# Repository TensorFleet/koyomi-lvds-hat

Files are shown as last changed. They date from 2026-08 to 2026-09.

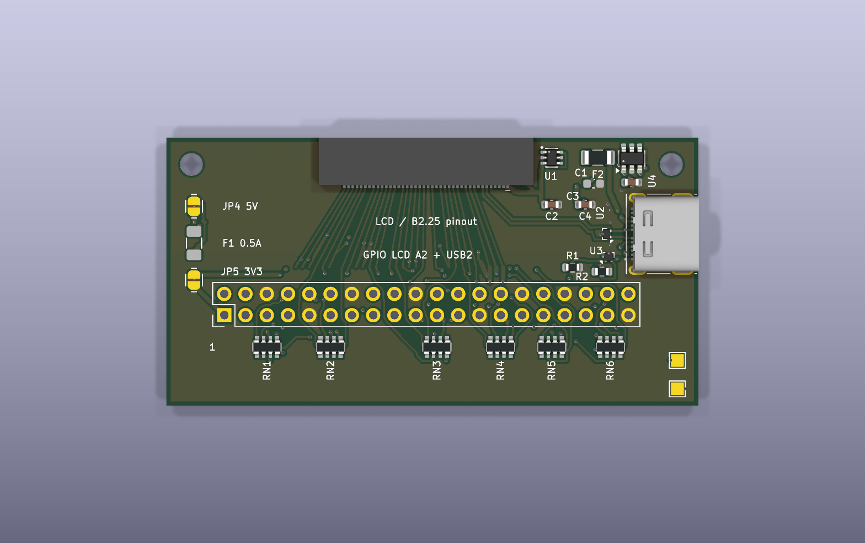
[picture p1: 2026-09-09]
gpio-breakout-a2-b225/renders/qualification-fixes-top.png

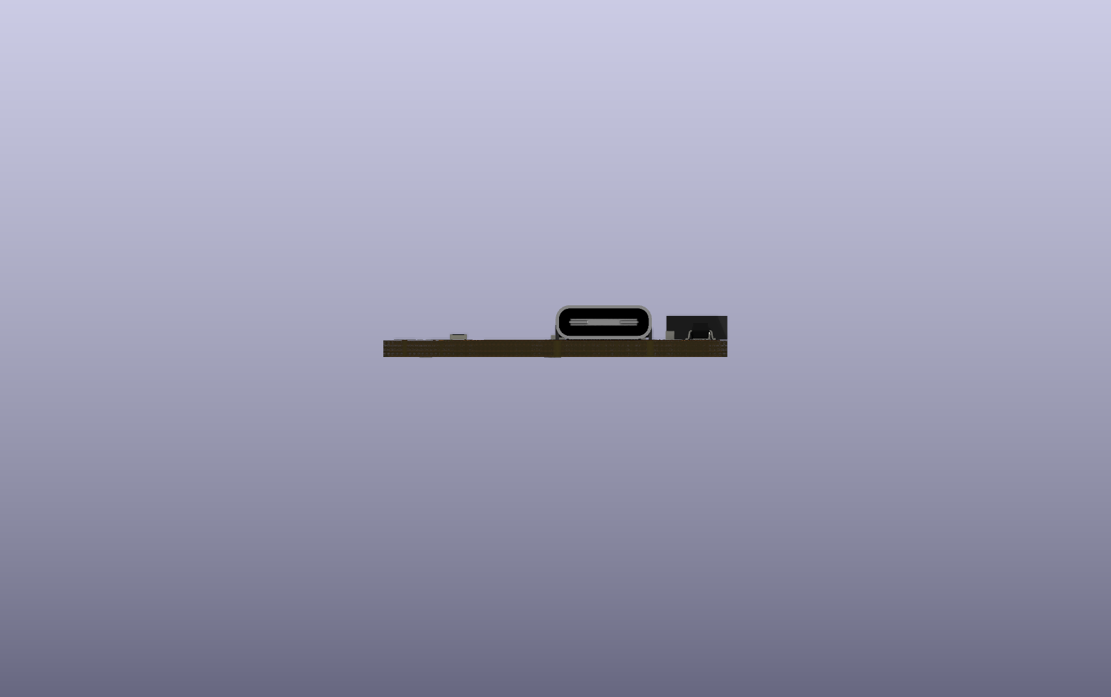
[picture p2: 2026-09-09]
gpio-breakout-a2-b225/renders/qualification-fixes-right.png

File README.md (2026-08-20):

# Project Koyomi - display testing hat

This is the first part of the development of Project Koyomi, read [this blog post](https://blog.exentio.sexy/2023/12/11/project-koyomi-planning.html)
for more.  
The purpose of this Raspberry Pi hat is to test and play around with the
display of the Vaio P before further development of the motherboard.  

The board is currently tested and working [as shown here](https://blog.exentio.sexy/2024/05/09/project-koyomi-update-3.html)!

The board uses Texas Instruments' SN75LVDS83B LVDS transmitter using the Pi's
DPI signals to send video out to the display. The final motherboard will use a
DVI receiver to free up the Raspberry's GPIO, a small converter board is in
development and [you can find it here](https://github.com/exentio/koyomi-hdmi-lvds).  

The display connector is made by I-PEX, and the model numbers are
`20374-030E-31`/`20374-R30E-31`, they're the same but the 0 variant seems to be
more common.  
The display, in my case a LT080EE04100 by Toshiba (it should be the same for
all Vaio Ps), has no backlight driver, and for that the backlight pins are
broken out, allowing testing of different drivers.  
The driver will be controlled using software I2C since all the hardware I2C
pins are already used by DPI. The assigned GPIOs are 23 for SDA and 24 for SCL.
More info about software I2C on [this page](https://learn.adafruit.com/raspberry-pi-i2c-clock-stretching-fixes/software-i2c).

The current settings used in `config.txt` (on top of the default) is:  
```
dtparam=i2c_arm=off
dtparam=spi=off
display_auto_detect=0
dtoverlay=vc4-kms-dpi-generic
dtparam=hactive=1600,hfp=32,hsync=65,hbp=97
dtparam=vactive=768,vfp=1,vsync=1,vbp=8
dtparam=width-mm=182,height-mm=87
dtparam=clock-frequency=83600000,rgb666
framebuffer_width=1600
framebuffer_height=768
dtoverlay=i2c-gpio,i2c_gpio_sda=23,i2c_gpio_scl=24
disable_overscan=1
```
---

Huge thanks to Arya ([@CRImier](https://github.com/CRImier)) for her help during most phases of the design!

---

## Note on this copy (TensorFleet)

This is a **modified copy** of [exentio/koyomi-lvds-hat](https://github.com/exentio/koyomi-lvds-hat),
redistributed under CERN-OHL-S-2.0. It exists because GitHub would not let us fork the upstream
repository (`403: You can't fork this repository at this time`), so we could not open a pull request.

**Modification made** (CERN-OHL-S-2.0 §3.3 requires modifications to be identified):

- `Add F.Mask to DLP2ADN121HL4L pads so FL1/FL2 are solderable` — the
  `Murata_DLP2ADN121HL4L` footprint declared its pads as `(layers "F.Cu" "F.Paste")` with no
  `"F.Mask"`, so no solder mask openings were generated for FL1/FL2 and all 16 pads were covered by
  solder mask. Fixed in the library footprint and in both placed instances. Exporting the F.Mask layer
  before and after gives 197 → 213 flashes: exactly 16 new openings, all at the FL1/FL2 pad
  coordinates, nothing else changed.

  Found when JLCPCB flagged it during production-file preparation for a batch of these boards. Note
  that KiCad's DRC does **not** check for missing solder mask openings, so this passes a clean DRC.

Everything else is unmodified upstream work by Exentio. `gerbers/` is upstream's snapshot and has
**not** been regenerated, so it still reflects the pre-fix state — regenerate from source before
fabricating.

Upstream author: if you're reading this, the fix is a two-line change and we'd happily send it as a PR
if forking becomes possible. Thanks for publishing the design.

## TensorFleet compact RGB variant

`variants/koyomi-lvds-hat-rgb-compact-r2.0/` is a fabrication-closed compact
fork of the tested RGB/DPI design. It replaces the 2×20 Raspberry Pi header
with the carrier's 40-contact FH41 FFC, consolidates the system connection into
one harness, and demonstrates a 65.0 × 28.25 mm half-area floorplan. See the
variant README for its exact status and routing gate.

`variants/koyomi-lvds-hat-rgb-compact-r2.1-single-side/` preserves that outline
and interface while moving every fitted SMD component to the front. It is the
single-side-assembly successor and remains fabrication-closed until routing and
release verification are complete.

`variants/koyomi-lvds-hat-rgb-compact-r2.2-backlight-ffc/` adds one keyed
12-contact FFC connector for the complete legacy J5/J6 LCD-backlight harness:
VCD1–VCD6, VAD, 5 V, ground, PWM, enable, and the preserved unused contact.
It remains a single-side, half-area floorplan and is still fabrication-closed
pending native routing and release verification.

`variants/koyomi-lvds-hat-rgb-compact-r2.6-production/` is the current compact
RGB fabrication candidate. It is fully routed, keeps all 23 fitted parts on the
top side, passes zero-error DRC/ERC and the routed interface audit, and restores
all panel-sideband and backlight endpoints through the consolidated cables. It
must be paired with CM5 carrier B2.2; see the variant README and the checksumed
`fab/r2.6-compact-rgb-production-jlc-candidate/` package before quoting.

`variants/koyomi-lvds-hat-rgb-compact-r2.7-30pct-floorplan/` is an experimental
58.0 × 22.2 mm-base successor that reduces R2.6 PCB area by 29.33% while retaining
all 23 fitted parts on the top side, all three cable connectors, and four
mounting holes. Its placement is physically DRC-clear, but its 138 connections
are intentionally unrouted; it is a mechanical study and must not be fabricated.

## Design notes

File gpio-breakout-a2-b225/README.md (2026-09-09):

# GPIO LCD bench adapter A2 — B2.25 numbered interface

This Raspberry Pi GPIO addon drives the separately updated LCD/Combined
peripheral C1 board. It preserves A1 in `../gpio-breakout`. Its 40-contact Samtec
interface follows the corrected B2.25 allocation; historical Hirose LCD boards
are incompatible.

**Qualification corrections implemented; not fabrication released.** The saved
JLC stackup, power widths, J1 paste, USB contact routing and startup circuit are
corrected. Six Pi-side display resistor arrays provide tuning options. Native
DRC has **0 errors/0 opens** and ERC has **0 active errors**. Hardware USB/power,
display and installed cable qualification remain open. See the
[current review and exact source hashes](reports/qualification-fixes.md) and
[bench procedure](reports/bench-qualification-plan.md).

## Interface and use

J1 is **Samtec ZF5S-40-01-T-WT-K-TR/C3169111**. USB uses VBUS pins 1–4,
D−6 and D+7; grounds are 5/8. LCD power and GPIO use pins 9–40. All 40 numbered
functions are preserved. [Pinout](interface-pinout.csv) lists physical Pi header
pins and the updated power/series-element paths. The native comparison is in
[interface-audit.json](reports/interface-audit.json).

J3 is **Molex 1054500101/C134092**. Connect a normal USB-A-to-C cable from the Pi
host port; the GPIO header itself does not carry USB. This is USB2 pass-through
with protection, not a hub. Both CC contacts have independent 5.1 kΩ pulldowns.
TPD2EUSB30 arrays protect data and CC; no whole-board ESD compliance is claimed.

RN1–RN6 insert one isolated **0 Ω** element on each of GPIO0–21, with GPIO0/1
named ID_SD/ID_SC. Their six four-element arrays are `4D03WGJ0000T5E/C1952`.
Select nonzero source values only after confirming the Pi/display timing and
coordinating C1's receiver-side resistor banks. Software must select the
corresponding alternate functions and display mode.

## Power and assembly

- Scope is **low-power USB2 bench use**. Full downstream USB-A load capacity
  is not provided. The 0.5 A PTC is not a precise current limit.
- USB VBUS passes through F2, TPS22918DBVR/C131941 and the existing LM66100
  reverse blocker. A 10 nF CT capacitor targets a typical 26.55 ms 10–90% rise
  at 5 V. QOD is unconnected. Actual startup current, host droop and load voltage
  still require measurements; this circuit does not implement USB enumeration.
- **JP4 (5 V) and JP5 (3.3 V) default OPEN.** Close only when the Pi is the sole
  source of those LCD supplies. Keep open for independently powered LCD
  electronics; closed links are not automatic reverse-current protection.
  JP4 includes F1, the retained 0.5 A PTC. USB supply remains separate.
- J2 is a hand-fit 2×20 Pi header/stacking socket. No particular stacking socket
  or Pi mechanical fit has been qualified. Pin 1 is marked. TP4/GND and
  TP5/Pi3V3 remain.
- J1's 42 pads include paste. C1's latest J401 also has 42 paste-enabled pads;
  the earlier peer paste finding is closed. Stencil and exact-part sourcing
  belong in the eventual gated fabrication package.

## Verification and limits

The 63.5×32 mm board has 27 footprints. All 193 numbered pads match the native
schematic XML and all 40 interface functions match. Native DRC retains 13
library snapshot warnings; ERC retains 25 library snapshot differences and
four intentionally unused Pi GPIO label warnings. The previous exact
TI-documented ST-to-ground exclusion remains; no global rule was weakened.

The saved four-layer JLC04161H-7628 construction is verified. Main USB pair
width/gap remains 0.2774/0.20 mm; minimum track width is 0.20 mm, ordinary via
drills are 0.30 mm. B6/B7 planar branches shortened to 1.588/4.312 mm, but B7
has two transitions while B6 has none. Coplanar ground is interrupted. These
geometry results do not qualify uniform impedance or the assembled channel.

[Current top](renders/qualification-fixes-top.png),
[USB-entry side](renders/qualification-fixes-right.png) and
[native schematic](renders/schematic/gpio_breakout.svg) reflect the final sources.
J1 is still a nominal envelope, not detailed Samtec CAD. J2 has no chosen socket
model. J3 uses the unmodified official Molex STEP with its mouth facing outward
at X113.55 mm, 0.05 mm past the board edge; plug-shroud clearance needs checking.

The catalog cable candidate is
[Samtec FJH-40-R-03.00-4](https://www.samtec.com/products/fjh-40-r-03.00-4),
76.2 mm. Both connectors match its manufacturer mating family, but installed
contact faces, pin-one arrangement, length and latch/fold clearance remain
unverified. Custom harnesses and repinning are prohibited. Physical continuity
is a TODO after cable selection and is not the sole release blocker.

## Reproduction and release

All native edits and checks are instrumented. Sources, current reports and
renders are hash-bound in the telemetry artifact manifest. Tools under `tools/`
are audited sequential revision steps, not a single idempotent generator.
Do not rerun historical netlist import/routing on the completed board. Use the
pinned September 5 KiCad CLI through `KICAD_CLI`; see
[the runtime record](reports/runtime-and-review.md). No shared installation was
modified. Standard package models were copied into project-relative paths.

The authoritative `gpio-breakout-a2` contract in
[private interconnect PR34](https://github.com/TensorFleet/vaio_p_modding/pull/34)
retains the hardware and installed-cable qualification hold. No Gerbers, drill,
BOM, CPL or JLC upload were produced during these corrections. Before any
fabrication generation, run `scripts/check_interconnect_release.py --board
gpio-breakout-a2` in that repository; it must pass. Older reports are historical
when their source hashes differ from the current review.

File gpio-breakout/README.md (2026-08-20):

# koyomi gpio-breakout A1 — 40-pin FFC to Pi GPIO bench adapter

Bench adapter: the carrier/LCD system's 40-contact FFC (Hirose
FH41-40S-0.5SH(05), C596805 — the JDISP1/JFFC1 interconnect) broken out 1:1 to
a standard Raspberry Pi 40-pin 2.54 mm header, so a stock Pi can drive the
Koyomi LVDS chain over the production FFC, or probe a carrier's display FFC.

**A1 addresses the 2026-08-20 A0 design review**: 63.5 × 32 mm, **4-layer**
(F sig / In1 solid GND plane / In2 GND pour / B sig+pour), corrected FH41
land pattern (0.30 × 0.65 copper, 0.25 paste via paste-margin), fused and
cuttable power links, all connector pins connected (pads 41–50 shield → GND),
FH41 symbol pins retyped passive.

## Gates (this commit, reproducible)

- Errors-only ERC: 0. Errors-only DRC: **0 violations, 0 unconnected, 0
  footprint errors** (`kicad/drc-errors.rpt`).
- All-severity DRC: 30 cosmetic silkscreen warnings, **zero dangling copper**
  (`kicad/drc-all.rpt`). All-severity ERC: 31 library-snapshot notices
  (`kicad/erc-all.rpt`) — recorded, not waived.
- NOT fabrication-released: the interconnect contract entry (registered in
  vaio_p_modding) pins the cable question — FH41 is specified for shielded
  0.3 mm FFC with ground contacts; an exact shielded cable P/N (or a reviewed
  decision to accept unshielded AWM 20624 for bench-only use) is required
  before Gerber/BOM/CPL generation.

## Power (new in A1)

Pi → FFC power is **fused and severable**:

- `JP4` (5V LINK) and `JP5` (3V3 LINK): solder jumpers, **bridged by default**
  so the adapter works out of the box; **cut them when the LCD chain is
  powered externally** (backside silk says so) to prevent backfeeding the Pi.
- `F1`: 0.5 A PTC polyfuse (1206) in the 5 V path — matches the FH41 0.5 A
  contact rating. Budget: serializer ≈50 mA on 3V3; backlight loads belong on
  a separate supply, not through this adapter.

## The three special pins — jumpers OPEN by default

FFC 17/34/39 are PANEL_ID0/PANEL_ID1/LCD_INS in the FFC system but 3V3/GND/GND
on a real Pi. They are isolated behind default-OPEN solder jumpers JP1–JP3
with test pads TP1–TP3 (TP4 GND, TP5 3V3 alongside). Close JP1/JP2 to strap
IDs, JP3 to report "panel inserted". Open = safe, and correct for the
retrofit (straps ignored, WP-003e).

## Assembly definition

- **J1 (FH41, C596805): JLC SMT-placed** — the only machine-placed part
  besides F1/JP jumper pads.
- **J2: DNP for assembly — hand-fit.** For riding a Pi, solder a 2×20
  **stacking socket** from the BOTTOM face (exact P/N to be pinned at order
  time); for cable use, a plain 2×20 pin header on top. Pin 1 = square pad,
  marked `1` on silk.
- FFC contacts face DOWN (silk marked) — same bottom-contact convention and
  cable fold rules as the carrier↔LCD link.

Generated headlessly (tools/: netlist_def_bo, gen_sch_bo, gen_pcb_bo,
route_board + pre-lay scripts); Freerouting 2.2.4 jar SHA-256 verified. GND
mid-row pads are stitched to the In1 plane with dedicated vias; power runs are
hand-placed locked copper laid before autorouting.

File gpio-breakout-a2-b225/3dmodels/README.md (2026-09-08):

# Model provenance

- `Molex_1054500101_official.stp`: unmodified Molex manufacturer STEP supplied
  with the USB-C part drawing. SHA-256 and fitted feet/shell/mouth evidence are
  in `../reports/usb2-model-audit.json`.
- `ZF5S-40-01-nominal-envelope.wrl`: existing conservative Samtec envelope;
  not vendor CAD and not proof of mating, latch or cable clearance.
- `standard/*.step`: unmodified KiCad standard 3D library models for SC-70-6,
  DRT-3 and 0603 passive bodies. Exact source-library names and file hashes are
  in `../reports/usb2-standard-models.json`. These are visualizations, not
  manufacturer metrology. KiCad libraries are distributed under CC BY-SA4.0
  with the KiCad libraries exception; see https://www.kicad.org/libraries/license/.

Native top/USB-side views show the saved model placements. J3 has only0.05mm
mouth overhang; the separate enclosure/plug-shroud fit still needs review.

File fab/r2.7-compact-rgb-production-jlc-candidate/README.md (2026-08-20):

# Compact RGB LCD R2.7 JLCPCB fabrication candidate

Upload the Gerber ZIP, `assembly/bom.csv`, and `assembly/positions.csv`. Select **four layers**, 1.6 mm, ENIG, a **0.20 mm minimum via-hole process**, ordinary tented vias, and **top-side Economic PCBA**. Enable **Confirm Production File** and manual parts-placement confirmation.

The board is electrically gated for fabrication: zero DRC errors, zero unconnected pads, zero exclusions, zero ERC errors, and the eleven-net routed-interface audit passes. The 13 all-severity DRC warnings are inherited library-copy mismatches and are retained in the report.

This is a fabrication-ready prototype, not final system approval. The mating B2.2 carrier and straight-through 40-contact cable are required. The external backlight circuit must implement the documented LCD_INS# pull-up and hardware interlock. Verify live JLC inventory, especially private-library connector C5311655, before checkout. The 2026-08-20 live check found C5311655 at stock 0 with a 442-piece pre-order minimum and C710576 at stock 0 with a 23-piece consignment minimum. The PCB is ready to fabricate; PCBA must wait until those exact parts are received.

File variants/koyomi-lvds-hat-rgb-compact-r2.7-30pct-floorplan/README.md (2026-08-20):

# Koyomi RGB/DPI LVDS — compact R2.7 production candidate

R2.7 forks the electrically complete R2.6 production candidate into a
smaller mechanical envelope without altering R2.6. It retains the same
schematic, connector identities, pin maps, and fitted component set.

## Mechanical target

- R2.6 outline: **65.0 × 28.25 mm = 1836.25 mm²**.
- R2.7 base rectangle: **58.0 × 22.2 mm = 1287.6 mm²**.
- `JFFC1` support tab: **20.0 × 0.5 mm = 10.0 mm²**.
- Actual board area: **1297.6 mm²**, a **29.33% reduction**.
- Copper: four layers (`F.Cu`, `In1.Cu`, `In2.Cu`, `B.Cu`).
- Assembly: **23 fitted parts, all on the top side**.
- Four mounting holes retained.

The three production cable connectors remain at board edges: `JFFC1` for the
system harness, `J2` for the panel, and `JBL1` for backlight/sideband support.
All three cable openings face their assigned board edge. `JFFC1` is rotated
180° from the first floorplan and sits behind a shallow local support tab so
its shield pads retain edge clearance. Their authoritative
edge and rotation record is `edge-connector-orientations.json`; a connector
opening toward the board interior blocks routing and fabrication.

## Status

This revision is fully routed and approved as a **fabrication-ready
prototype**. Native KiCad reports zero electrical/clearance errors and zero
unconnected pads; errors-only ERC is also zero. The routed interface,
straight-through system interconnect, connector placement, and top-only
assembly gates pass. The reproducible JLCPCB package is generated by
`../../scripts/build_r2_7_jlc_candidate.py` into
`../../fab/r2.7-compact-rgb-production-jlc-candidate/`.

JLCPCB assembly still requires parts sourcing before checkout. As checked on
2026-08-20, `J2` (`C5311655`) has zero warehouse stock and a 442-piece
pre-order minimum, while `FL1`/`FL2` (`C710576`) have zero warehouse stock and
a 23-piece consignment minimum. Do not silently substitute either part:
`J2` is the exact panel-mating connector and the filter pinout is part of the
LVDS path. See `FABRICATION_STATUS.md` for the release evidence and procurement
boundary.

`scripts/make_r2_7_floorplan.py` records the layout mutation and
`scripts/finish_r2_7.py` reproducibly closes the final routes through KiCad's
official IPC API. Fresh KiCad renders and reports live in `renders/` and
`reports/`.

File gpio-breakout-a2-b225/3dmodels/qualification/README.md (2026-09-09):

# Standard package models

These unmodified files were copied from the pinned KiCad September 5, 2026
bundle. Their original license and author notices remain in each STEP header.
The capacitor, fuse and SOT-23 models use the stated CC-BY-SA 4.0 terms with
the KiCad design exception. The 2017 kicad StepUp resistor-array model uses
GPL-3.0-or-later with the embedded-design exception stated in its header;
a copy of GPLv3 is included here. These are package visualizations, not vendor
mechanical qualification of the assembled board.

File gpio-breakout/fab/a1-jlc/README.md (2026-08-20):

# gpio-breakout A1 — JLCPCB order package (2026-08-20)

- PCB: 63.5 x 32 mm, 4 layers, min drill 0.30 mm (standard capability, no
  fine-hole surcharge). Gerbers: `gpio-breakout-a1-gerbers.zip`.
- Assembly: TOP side, TWO placed parts only — J1 (FH41 FFC receptacle,
  C596805, extended part) and F1 (0.5 A PTC 1206, C106264; alternate
  C315893). `assembly/bom.csv` + `assembly/positions.csv`.
- NOT placed: J2 (hand-fit 2x20 stacking socket from the bottom face),
  JP1-JP5 (bare solder jumpers; JP4/JP5 factory state = bridged copper,
  JP1-JP3 open), TP1-TP5, H1/H2.
- Order flags: enable "Confirm Production File"; review parts placement
  manually (FFC orientation: opening toward top board edge).
- Cable note (contract remediation): the 40P 0.5 mm FFC purchase is a
  separate decision — shielded per Hirose D31607 preferred; unshielded
  AWM 20624 acceptable bench-only. This package does not order cables.

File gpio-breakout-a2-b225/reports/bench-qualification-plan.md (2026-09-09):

# GPIO A2 bench qualification after the circuit corrections

This is a test procedure, not a record of completed hardware measurements.
Scope remains low-power USB2 bench use. Downstream USB-A load capacity is not
increased by the startup switch or the 0.5 A PTC.

## Bring-up and power

1. With the LCD and USB loads disconnected, confirm the fitted parts and both
   default-open LCD supply links JP4/JP5. Establish a common ground and verify
   the selected power arrangement does not connect two active LCD supplies.
2. Observe upstream VBUS, U4 output (`USB_VBUS_SOFT`), and the peer's USB rail
   simultaneously during cold plug-in. Capture input current with a current
   probe or calibrated shunt. Repeat in both USB-C plug orientations.
3. U4 TPS22918 precedes the existing LM66100 reverse blocker. Its 10 nF CT
   capacitor targets a typical 26.55 ms 10–90% output rise at 5 V per TI's
   datasheet. For 120.2 uF nominal peer capacitance this corresponds to about
   18.1 mA average capacitor charging current during that interval, before
   operating load. This is a typical calculation, not a guaranteed peak limit.
4. Verify startup, reset, disconnect, rapid reconnect and an externally powered
   peer. Check host voltage droop, reverse leakage, peer undervoltage and the
   downstream rail decay. QOD is deliberately unconnected. The load switch
   does not enforce USB enumeration current limits; the PTC is not a precision
   current limiter.
5. Log settled upstream/peer voltage and input current at idle and during the
   actual bench workload. Do not infer a supported 500 mA load from the fuse's
   hold-current marking. Record ambient and F2/U1/U4 temperatures.

## USB2

Use the intended Pi host and catalog cables. Confirm high-speed enumeration,
then run repeated transfers through the hub and keyboard activity in both
Type-C orientations. Record USB speed, transfer errors, disconnects and host
logs. Inspect the full assembled channel with appropriate USB measurement
fixtures if a compliance claim is required. A board DRC pass is not an eye test.

## Display

RN1–RN6 provide one isolated series element for each of GPIO0–GPIO21 (GPIO0/1
are named ID_SD/ID_SC). Two unused elements remain unconnected. The initial
0 ohm population preserves the existing electrical interface while providing
source-side tuning; it is not a claim of impedance matching.

Confirm the Pi model, GPIO drive configuration, LCD identity and actual pixel
clock before selecting nonzero values. Existing project context suggests an
83.6 MHz RGB666 1600x768 mode, but it has not been confirmed for this new setup.
Capture clock/data at the receiving device, check its setup/hold requirements,
and compare 22/33/47 ohm source populations as needed. Reconcile the existing
receiver-side 47 ohm arrays on C1; do not assume two resistor banks constitute
correct source termination. Run stable patterns and the intended workload.

## Catalog cable and mechanical check

Both J1 and C1 J401 specify Samtec ZF5S-40-01-T-WT-K-TR. Samtec lists FJH as the
mating family; FJH-40-R-03.00-4 is the existing 76.2 mm catalog candidate. Verify
contact faces, pin-one alignment, usable length and latch/fold access in the
actual bench arrangement. Use the manufacturer drawings, not the nominal 3D
envelope, to assess the connector. Cable continuity is a TODO after the cable
choice, not the sole fabrication blocker. No custom or repinned cable is
permitted.

Record equipment, exact host/cable/peer revisions, captures and pass/fail values.
Do not fill this checklist with inferred or simulated measurements.

References: [TI TPS22918](https://www.ti.com/lit/ds/symlink/tps22918.pdf),
[Samtec connector](https://www.samtec.com/products/zf5s-40-01-t-wt-k-tr),
[Samtec catalog cable](https://www.samtec.com/products/fjh-40-r-03.00-4).

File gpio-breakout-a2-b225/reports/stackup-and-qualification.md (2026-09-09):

> Historical stackup-stage record. The [later qualification corrections](qualification-fixes.md) supersede its USB, startup, display-array and C1 paste status.

# GPIO A2 stackup correction and qualification

2026-09-09. **Stackup correction and power-width improvements verified; manufacturing qualification remains blocked.** Scope: low-power USB2 bench use, with C1 as the LCD/USB peer. No fabrication files or JLCPCB upload were produced.

Source PCB SHA-256: `6df373e8b229327e0325547ae18f7e711fa34f61f5d1cccadf840d49595d9113`.
Schematic SHA-256: `7d6f4f5814031e3394d59b90022250afa140a6cd729119d2978a34c2cbb0e7e7` (unchanged).

## Corrections verified

The editable PCB now uses JLC04161H-7628: 35/15.2/15.2/35 µm copper, 0.2104/1.065/0.2104 mm dielectric, and dielectric constants 4.4/4.6/4.4. The outer layers are prepreg and the middle layer is core. Impedance control is enabled. Values were rechecked against [JLC's published construction](https://jlcpcb.com/impedance) and read back through native KiCad.

Solder-mask permittivity is 3.8. KiCad's flat layer approximation uses the published 15.24 µm thickness above traces; JLC specifies 30.48 µm above substrate and between traces. The copper/dielectric sum is 1.5862 mm; adding the flat mask approximation gives 1.61668 mm. Order by **nominal 1.6 mm and named JLC stack**, not by requesting 1.61668 mm fabrication. The inherited loss tangent of 0.02 is not a measured material model. The native stack now matches the calculator inputs, but this alone cannot qualify the whole channel at 90 Ω.

293 existing power segments were widened to 0.25–0.50 mm according to available clearance; most unrestricted runs use 0.50 mm. Narrow fanouts remain, including roughly 10 mm FFC escapes on the 5 V and 3.3 V rails. No signal routes, connector placements, pad geometry, net assignments, or schematic connections changed. All 1,353 tracks, 74 vias, 18 footprints and four zone definitions remain. Three ground fills were regenerated for the new clearances.

KiCad converted the inherited thermal default on JP4/JP5's four custom pads from 45° to 90°. Native setter round-trip attempts did not restore it. The audit permits only these four exact changes after confirming none of their nets has a copper zone; no thermal connection exists there to change. The project file also gained native version metadata/default rule entries. No electrical rule was weakened.

See [native stack and preservation checks](stackup-qualification.json), [width changes](power-width-qualification.json) and [independent pin checks](qualification-interface.json).

## Check results

| Check | Result |
| --- | --- |
| Saved JLC copper/dielectrics/mask inputs | PASS |
| Expected changes only | PASS, including the explicitly checked thermal-default conversion and zone refills |
| Native DRC, pinned September 5 build | 0 errors, 0 opens; 6 library snapshot warnings |
| Native ERC, pinned build | 0 active errors; 21 existing warnings; the prior exact unused-ST exclusion is unchanged |
| Schematic/PCB parity | All 135 numbered board pads pass; all 40 FFC functions pass |
| J1 paste | All 42 GPIO connector pads have paste |
| USB reference ground | 698/698 F.Cu-to-In1 and 102/102 In2-to-B samples covered outside transition antipads |
| USB full channel | NOT QUALIFIED: branch length, discontinuities and complete peer/cable channel remain |
| Power | Positive-conductor DC model completed; full assembled budget and inrush NOT QUALIFIED |
| DPI | All 22 driven lines connected; source termination and receiver timing NOT QUALIFIED |
| Mechanical mating | USB opening remains outward; Samtec detailed model and installed catalog cable fit remain open |

The development-build cross-check also reported zero electrical/geometry errors, but 9 DRC and 43 ERC library/configuration warnings because its standard libraries were not enabled. Both raw reports are retained; the pinned results above use the established library environment.

## Remaining electrical work

**USB branches:** actual junction-to-contact planar branches are A6/A7 ≈1.03 mm, B6 **6.678 mm**, and B7 **9.776 mm**; each B branch also uses two through-vias. These are actual branch lengths, not A/B endpoint-length subtraction. They exceed the 200 mil (5.08 mm) stub recommendation in [TI's USB2 layout guide](https://e2e.ti.com/cfs-file/__key/communityserver-discussions-components-files/171/USB-2.0-Board-Design-and-Layout-Guidelines.pdf). This is a design-screen failure, not a measured USB compliance failure. Rework the reversible-contact joins or select a qualified footprint/connector solution, then recheck clearance, pairing, ground return and total channel. No routing change to the data pair is claimed in this correction. Main-path skews remain 1.302 mm (A) and 1.795 mm (B). Coplanar ground is present at only 283/337 main-pair samples, so the calculator result is not a uniform impedance guarantee.

**Voltage drop:** the widened USB positive copper path has a conservative single-path estimate of 0.0627 Ω at 60 °C, assuming 20 µm via plating. Parallel copper is ignored. Including the review's 0.75 Ω PTC resistance screen gives about 0.081 V at 100 mA, 0.203 V at 250 mA, or 0.406 V at 500 mA, **before** ideal diode, connectors, cables, ground return and C1 losses. These are calculation scenarios, not supported current ratings. F2 remains 0.5 A hold and is not a regulated limiter. The actual host/load and minimum receiver voltage must close the budget. See [power-path calculation](power-path-qualification.json).

**Inrush:** C1's prior schematic audit identifies 120.2 µF directly on its downstream USB rail. The C1 schematics remain unchanged. Charging that nominal capacitance to 5 V requires 601 µC; a 1 ms rise implies 0.601 A average capacitor current, plus operating load. The [LM66100](https://www.ti.com/lit/ds/symlink/lm66100.pdf) provides reverse blocking, not an adjustable current-limited charging ramp. Add controlled inrush charging or qualify plug-in current and host droop with the actual assembled load. Low steady-state load does not eliminate this issue. No scope measurement was available.

**DPI:** all 22 driven paths were traced from J2 to J1. There are still no source-side series components; C1's 47 Ω arrays are at the receiver. The Pi model, drive settings and panel mode/pixel clock have been requested. Source-side resistor provisions and their fitted values still need implementation/verification against those assumptions; 0 Ω options alone would not establish termination. The [Raspberry Pi DPI guide](https://pip.raspberrypi.com/categories/685-app-notes-guides-pcns-whitepapers/documents/RP-003471-WP/Using-a-DPI-display.pdf) establishes the configurable interface, not this cable's timing margin. See [DPI qualification record](dpi-qualification.json). No resistor arrays were added by this correction.

## Peer and assembly limits

C1 advanced to commit `ce6f1d0d` during this review. Its current J401 footprint was read natively, and all 40 contacts still match the unchanged C1 schematic export and GPIO functions. **C1 J401 has zero paste-enabled pads**, so its copy of the Samtec footprint still needs the solder-paste repair. C1's prior full-board manufacturing status refers to an older PCB hash and is not a fresh approval of its latest board. C1 source files were not edited here.

J1 on GPIO remains a nominal envelope, not a detailed manufacturer model. The official Samtec FJH-40-R-03.00-4 catalog cable remains the candidate; installed contact faces, available length and fold clearance require confirmation. Physical continuity is a TODO after the cable choice and is not, by itself, a release blocker. Custom harnesses remain prohibited. Samtec's stencil drawing specifies 0.15 mm while its product specification says 0.13 mm; the assembler must resolve that process discrepancy. GPIO paste apertures themselves are 1:1.

[Current top view](../renders/qualification-top.png) and [USB entry view](../renders/qualification-right.png) are native KiCad renders. J3 opens outward. F1/F2 have no body model in the top view; J1 is only an envelope. Renders do not close Samtec latch/cable or chassis fit qualification.

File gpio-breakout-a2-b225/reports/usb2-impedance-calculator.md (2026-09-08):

# USB2 manufacturing geometry reference

**Native stackup corrected on 2026-09-09.** The saved copper/dielectric
construction matches the profile below; see [native readback](stackup-qualification.json).
The corrected source still must not be described as a fully qualified 90-ohm
channel: breakouts, B-contact stubs and interrupted coplanar ground remain.

Read from the official [JLCPCB impedance calculator](https://jlcpcb.com/pcb-impedance-calculator)
on 2026-09-09. The [published stackup table](https://jlcpcb.com/impedance)
supplies the dielectric dimensions and dielectric constants.

Calculator inputs: rigid PCB, four layers, nominal 1.6 mm, outer copper 1 oz,
inner copper 0.5 oz, units mm. Selected profile **JLC04161H-7628**, standard,
finished thickness **1.59 mm ±10%**. A coplanar differential pair on L1,
referenced to L2, target **90 ohms**, trace edge spacing **0.20 mm**, and
trace-to-coplanar-ground spacing **0.25 mm**, returns trace width **0.2774 mm**.
The displayed rounded output gaps are 0.1999 and 0.2499 mm.

| Layer | Thickness (mm) | Relative permittivity |
| --- | ---: | ---: |
| L1 copper | 0.0350 | — |
| 7628 prepreg | 0.2104 | 4.4 |
| L2 copper | 0.0152 | — |
| Core | 1.0650 | 4.6 |
| L3 copper | 0.0152 | — |
| 7628 prepreg | 0.2104 | 4.4 |
| L4 copper | 0.0350 | — |

This is a geometry reference for the main outer-layer pair, not measured
impedance or USB compliance. Pad escapes, reversible-contact branches and
vias are discontinuities. L3 branches require their actual L4 ground return
to be reviewed. Manufacturing must confirm the selected materials and
finished geometry; the calculator's displayed 0.5% numerical tolerance is
not a fabrication impedance guarantee. The complete cable/FFC/peer channel
still needs qualification. No fabrication output was generated by this check.

**Implementation limit:** the native flat solder-mask layer uses JLC's 15.24 µm
above traces and Er 3.8; its calculator also models 30.48 µm above substrate
and between traces. The inherited loss tangent of 0.02 is unqualified.
See [remaining qualification results](stackup-and-qualification.md).

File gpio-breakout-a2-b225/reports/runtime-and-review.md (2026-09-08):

# A2 runtime and review record

The native board was migrated from A1 into this separate revision, then routed
and checked without editing PCB or schematic S-expressions. KiCad GUI Page
Settings supplied the schematic title/date and power/USB scope comments.

The existing carrier Python environment had mismatched schematic wrappers and
protobufs (missing BusEntryType). Its older parity API server did not open this
schematic. The Sept5 server with the then-current temporary b225 bindings also
failed decoding SchematicSymbolInstance. No shared runtime was modified.

An isolated bindings directory was copied from `/private/tmp/b225-kicad-python`
to `/private/tmp/gpio-addon-native-api`, then its generated protobuf modules
were rebuilt from `/private/tmp/b225-native-proto/api/proto` using the existing
`/private/tmp/b225-protoc/bin/protoc` and b225-api-venv's generator tools. The
new Homebrew protoc was incompatible with the older Python protobuf runtime,
so that failed attempt was replaced by the existing matching protoc.

The successful environment used:

- Python: `/private/tmp/b225-api-venv/bin/python`.
- PYTHONPATH: `/private/tmp/gpio-addon-native-api`.
- DYLD_FRAMEWORK_PATH: `/opt/homebrew/opt/python@3.14/Frameworks`.
- DYLD_LIBRARY_PATH: `/private/tmp/b22451-pinned-runtime`.
- PCB CLI: the existing `tools/kicad11-b2231-parity/KiCad.app` bundle.
- Schematic CLI: the existing `tools/kicad11-nightly-20260905/KiCad/KiCad.app` bundle.

Those are session paths, not a portable installation recipe. The final editable
KiCad files, local connector libraries and reports are the deliverables. Use a
matching official native API runtime to reproduce or extend these sources.

The initial route candidates exposed insufficient router clearance, an
underestimated custom solder-jumper shape, and blocked 0.5mm pitch fanout.
Native DRC rejected these attempts. The accepted route uses a reserved widening
fanout and ordinary through vias; remaining connections were closed using the
available via layers. The initial LCD-only A2 DRC had zero findings and zero unconnected
items. The later USB extension results supersede that state; see README and
current drc.json/erc.json. The final source hash is recorded in interface-audit.json.

Top and cable-entry-side images were visually reviewed. The gray rectangular
J1 body is a nominal envelope only. It contains no contact, latch, or aperture
geometry and cannot qualify physical mating. The exact official Samtec page
was inspected on 2026-09-08; its CAD downloads require an email/privacy-consent
submission. No email address was supplied or message sent. The future LCD
endpoint, exact catalog cable assembly and detailed model remain release gates.

Published telemetry contains this run's phase times, failures, script hashes,
and a source/artifact manifest. Unrelated parent-workspace inventory and its
private repository details are omitted from the public addon repository.

## USB input extension

The USB extension used the same isolated native IPC runtime and explicit
telemetry run 20260908T231349-8d8dcf94. It adds a protected upstream USB-C
input while preserving original LCD pad geometry and copper. Native netlist
import duplicated three custom footprints; restoring the original native
footprints and comparing every original footprint/copper item caught and
removed that regression. Symbol body graphics were also registered in local
coordinates after native schematic visual review exposed displaced graphics;
all electrical pin positions and IDs were preserved. Raw failed DRC/ERC
reports and revision scripts are retained as evidence, not accepted results.

The native GUI applied one narrow, commented ERC exclusion: the datasheet's
unused LM66100 ST-to-ground connection versus the existing GND power flag.
No global electrical rule or copper clearance was relaxed. Standard USB
protection body models were attached explicitly after checking that the
netlist import had omitted them. J3 uses the independently checked official
Molex model; J1 remains an explicitly unqualified nominal envelope.

Native physical stackup editing remains blocked. The saved generic dielectric
stack is not the selected JLC04161H-7628 process reference. Native IPC has no
implemented setter; GUI selection could not isolate this addon from another
unsaved design. That other design was not changed. Native launcher process
lifetimes overlap some separately recorded GUI action/selection phases; the
measured phase total is aggregated elapsed time, not exclusive runtime or CPU
time. Failed attempts remain visible in the telemetry.

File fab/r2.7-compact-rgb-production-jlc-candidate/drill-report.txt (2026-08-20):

Drill report for koyomi-lvds-hat.kicad_pcb
Created on 2026-08-20T19:01:19

Copper Layer Stackup:
    =============================================================
    L1 :  F.Cu                      front
    L2 :  In1.Cu                    in1
    L3 :  In2.Cu                    in2
    L4 :  B.Cu                      back

Drill file 'koyomi-lvds-hat-PTH.drl' contains
    plated through holes:
    =============================================================
    T1  0.200mm  0.0079"  (6 holes))
    T2  0.250mm  0.0098"  (169 holes))

    Total plated holes count 175

Drill file 'koyomi-lvds-hat-NPTH.drl' contains
    unplated through holes:
    =============================================================
    T1  2.750mm  0.1083"  (4 holes))

    Total unplated holes count 4

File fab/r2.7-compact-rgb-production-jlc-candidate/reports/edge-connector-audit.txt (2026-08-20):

{
  "result": "PASS",
  "board": "/private/tmp/koyomi-r27-finish.KVCgA2/repo/variants/koyomi-lvds-hat-rgb-compact-r2.7-30pct-floorplan/koyomi-lvds-hat.kicad_pcb",
  "connectors": {
    "JFFC1": {
      "x": 120.0,
      "y": 25.3,
      "rotation": 180.0,
      "layer": "F.Cu",
      "edge": "top",
      "opening": "outward"
    },
    "J2": {
      "x": 118.5,
      "y": 41.2,
      "rotation": 0.0,
      "layer": "F.Cu",
      "edge": "bottom",
      "opening": "outward"
    },
    "JBL1": {
      "x": 135.5,
      "y": 39.8,
      "rotation": 0.0,
      "layer": "F.Cu",
      "edge": "bottom",
      "opening": "outward"
    }
  },
  "interpretation": "Exact X/Y, rotation, F.Cu placement, assigned edge, and outward opening agree with the immutable R2.7 connector record."
}

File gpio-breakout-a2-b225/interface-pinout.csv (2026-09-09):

ffc_pin | signal | pi_physical_pins | power_path
1 | USB_VBUS |  | USB cable / F2 / TPS22918 / LM66100
2 | USB_VBUS |  | USB cable / F2 / TPS22918 / LM66100
3 | USB_VBUS |  | USB cable / F2 / TPS22918 / LM66100
4 | USB_VBUS |  | USB cable / F2 / TPS22918 / LM66100
5 | GND | 6/9/14/20/25/30/34/39 | direct
6 | USB_D_N |  | USB cable / ESD
7 | USB_D_P |  | USB cable / ESD
8 | GND | 6/9/14/20/25/30/34/39 | direct
9 | +5V_FFC | 2/4 | JP4 (open) + F1
10 | +5V_FFC | 2/4 | JP4 (open) + F1
11 | +3V3_FFC | 1/17 | JP5 (open)
12 | GND | 6/9/14/20/25/30/34/39 | direct
13 | GPIO23 | 16 | direct
14 | GPIO24 | 18 | direct
15 | ID_SC | 28 | source array (0R)
16 | GPIO2 | 3 | source array (0R)
17 | GPIO3 | 5 | source array (0R)
18 | GND | 6/9/14/20/25/30/34/39 | direct
19 | ID_SD | 27 | source array (0R)
20 | GND | 6/9/14/20/25/30/34/39 | direct
21 | GPIO4 | 7 | source array (0R)
22 | GPIO5 | 29 | source array (0R)
23 | GPIO6 | 31 | source array (0R)
24 | GPIO7 | 26 | source array (0R)
25 | GPIO8 | 24 | source array (0R)
26 | GPIO9 | 21 | source array (0R)
27 | GND | 6/9/14/20/25/30/34/39 | direct
28 | GPIO10 | 19 | source array (0R)
29 | GPIO11 | 23 | source array (0R)
30 | GPIO12 | 32 | source array (0R)
31 | GPIO13 | 33 | source array (0R)
32 | GPIO14 | 8 | source array (0R)
33 | GPIO15 | 10 | source array (0R)
34 | GND | 6/9/14/20/25/30/34/39 | direct
35 | GPIO16 | 36 | source array (0R)
36 | GPIO17 | 11 | source array (0R)
37 | GPIO18 | 12 | source array (0R)
38 | GPIO19 | 35 | source array (0R)
39 | GPIO20 | 38 | source array (0R)
40 | GPIO21 | 40 | source array (0R)

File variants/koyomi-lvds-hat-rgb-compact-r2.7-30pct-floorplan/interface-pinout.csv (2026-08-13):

ffc_pin | pi_physical_pin | signal | pi_gpio_or_role
1 | 1 | +3V3 | 3.3V power
2 | 2 | +5V | 5V power
3 | 3 | VSYNC | GPIO2 / BCM2_SDA
4 | 4 | +5V | 5V power
5 | 5 | HSYNC | GPIO3 / BCM3_SCL
6 | 6 | GND | ground
7 | 7 | B0 | GPIO4 / BCM4_GPCLK0
8 | 8 | G4 | GPIO14 / BCM14_TXD
9 | 9 | GND | ground
10 | 10 | G5 | GPIO15 / BCM15_RXD
11 | 11 | R1 | GPIO17
12 | 12 | R2 | GPIO18 / BCM18_PCM_C
13 | 13 | EN | GPIO27
14 | 14 | GND | ground
15 | 15 | GP22 | GPIO22 spare/test
16 | 16 | SDA | GPIO23 software I2C SDA
17 | 17 | PANEL_ID0 | panel identification strap 0
18 | 18 | SCL | GPIO24 software I2C SCL
19 | 19 | G0 | GPIO10 / BCM10_MOSI
20 | 20 | GND | ground
21 | 21 | B5 | GPIO9 / BCM9_MISO
22 | 22 | GP25 | GPIO25 spare/test
23 | 23 | G1 | GPIO11 / BCM11_SCLK
24 | 24 | B4 | GPIO8 / BCM8_CE0
25 | 25 | GND | ground
26 | 26 | B3 | GPIO7 / BCM7_CE1
27 | 27 | CLKIN | GPIO0 / ID_SD
28 | 28 | ENABLE | GPIO1 / ID_SC / DPI DE
29 | 29 | B1 | GPIO5
30 | 30 | GND | ground
31 | 31 | B2 | GPIO6
32 | 32 | G2 | GPIO12 / BCM12_PWM0
33 | 33 | G3 | GPIO13 / BCM13_PWM1
34 | 34 | PANEL_ID1 | panel identification strap 1
35 | 35 | R3 | GPIO19 / BCM19_PCM_FS
36 | 36 | R0 | GPIO16
37 | 37 | PWM | GPIO26
38 | 38 | R4 | GPIO20 / BCM20_MOSI_PCM_DI
39 | 39 | LCD_INS | panel insertion detect
40 | 40 | R5 | GPIO21 / BCM21_SCLK_PCM_DO

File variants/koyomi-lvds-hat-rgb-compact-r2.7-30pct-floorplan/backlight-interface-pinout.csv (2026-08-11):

ffc_pin | signal | legacy_source | role
1 | VCD6 | J5.1 | LCD backlight cathode/control channel 6
2 | VCD5 | J5.2 | LCD backlight cathode/control channel 5
3 | VCD4 | J5.3 | LCD backlight cathode/control channel 4
4 | VCD3 | J5.4 | LCD backlight cathode/control channel 3
5 | VCD2 | J5.5 | LCD backlight cathode/control channel 2
6 | VCD1 | J5.6 | LCD backlight cathode/control channel 1
7 | VAD | J6.1 | LCD backlight anode supply
8 | NC | J6.2 | legacy unused contact preserved as no-connect
9 | GND | J6.3 | ground return
10 | +5V | J6.4 | 5 V supply
11 | PWM | J6.5 | backlight brightness PWM
12 | EN | J6.6 | backlight enable

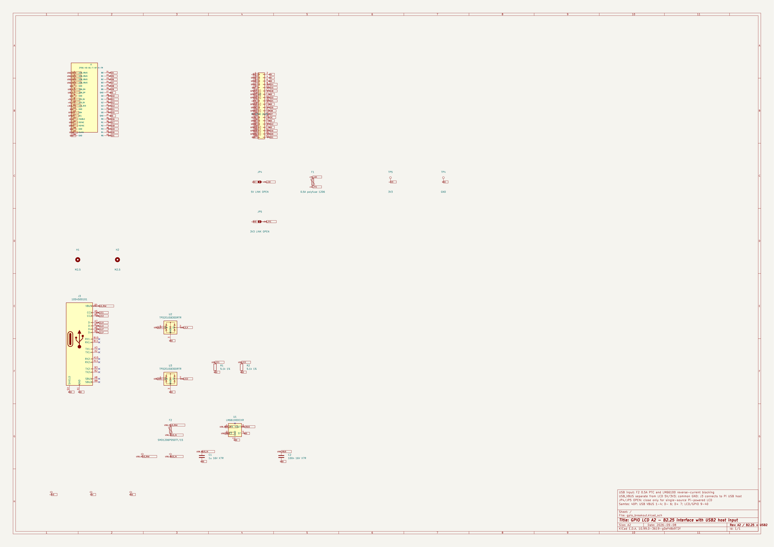
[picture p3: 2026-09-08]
gpio-breakout-a2-b225/renders/schematic/gpio_breakout.png

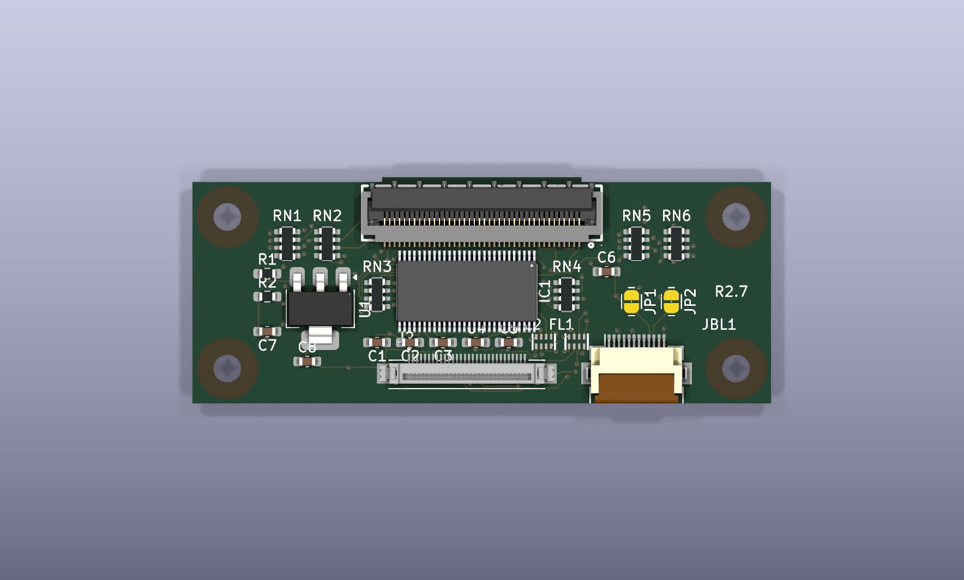
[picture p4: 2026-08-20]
fab/r2.7-compact-rgb-production-jlc-candidate/renders/top.png

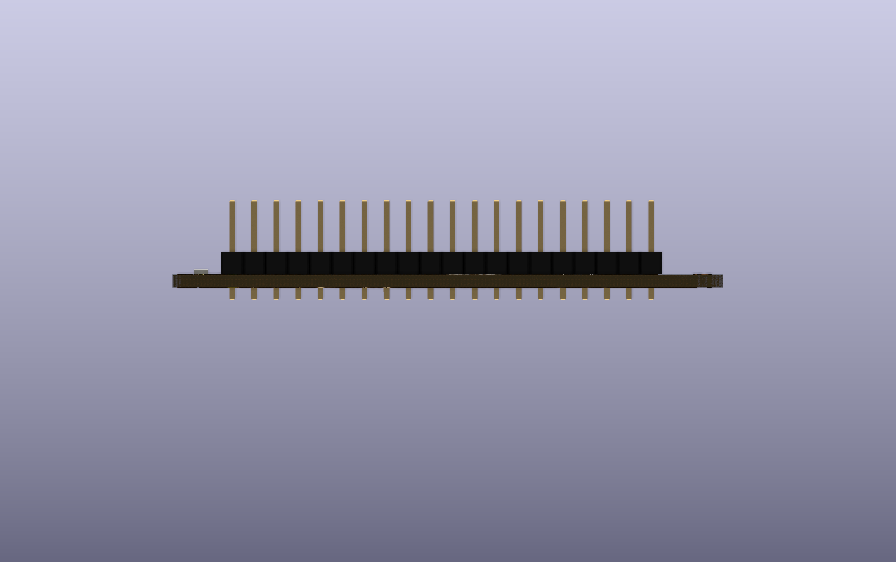
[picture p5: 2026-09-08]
gpio-breakout-a2-b225/renders/front.png

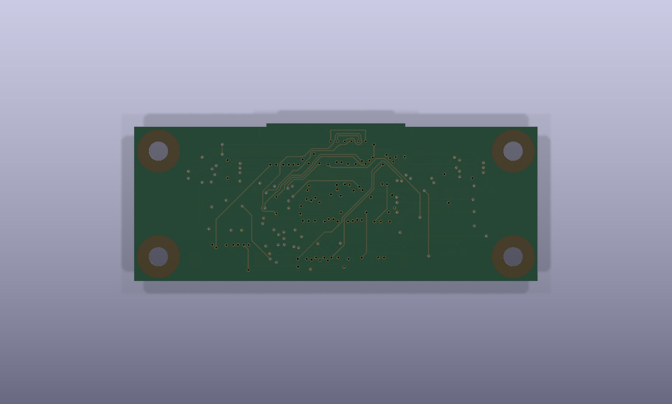
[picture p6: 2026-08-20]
variants/koyomi-lvds-hat-rgb-compact-r2.7-30pct-floorplan/renders/bottom.png

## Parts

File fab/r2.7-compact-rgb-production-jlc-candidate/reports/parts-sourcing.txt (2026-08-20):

JLCPCB live parts-library check: 2026-08-20
J2 C5311655 / I-PEX 20374-R30E-31: stock 0; pre-order minimum 442
FL1,FL2 C710576 / Murata DLP2ADN121HL4L: stock 0; consignment minimum 23
Do not substitute without a new footprint, pin-order, mating, and signal-integrity review.

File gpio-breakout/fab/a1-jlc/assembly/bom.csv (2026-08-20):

Comment | Designator | Footprint | JLCPCB Part #
0.5A PTC 1206 | F1 | Fuse_1206_3216Metric | C106264
FH41-40S-0.5SH(05) | J1 | FPC-SMD_FH41-40S-0.5SH | C596805

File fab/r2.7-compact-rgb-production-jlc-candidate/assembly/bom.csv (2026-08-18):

Comment | Designator | Footprint | JLCPCB Part #
1uF | C1,C4 | C_0603_1608Metric_Pad1.08x0.95mm_HandSolder | C1592
100nF | C2,C5 | C_0603_1608Metric_Pad1.08x0.95mm_HandSolder | C1591
10nF | C3,C6 | C_0603_1608Metric_Pad1.08x0.95mm_HandSolder | C1589
4.7uF | C7,C8 | C_0603_1608Metric_Pad1.08x0.95mm_HandSolder | C1705
DLP2ADN121HL4L | FL1,FL2 | Murata_DLP2ADN121HL4L | C710576
SN75LVDS83B | IC1 | TSSOP56 | C35164
I-PEX 20374-R30E-31 | J2 | I-PEX_20374-R30E-31 | C5311655
Hirose FH12-12S-0.5SH(55) | JBL1 | Hirose_FH12-12S-0.5SH_1x12-1MP_P0.50mm_Horizontal | C88360
Hirose FH41-40S-0.5SH(05) | JFFC1 | FPC-SMD_FH41-40S-0.5SH | C596805
4.7k | R1,R2 | R_0603_1608Metric_Pad0.98x0.95mm_HandSolder | C844791
47 ohm array | RN1,RN2,RN3,RN4,RN5,RN6 | R_Array_Convex_4x0603 | C425204
AP2114H-2.5 | U1 | SOT-223-3_TabPin2 | C460313

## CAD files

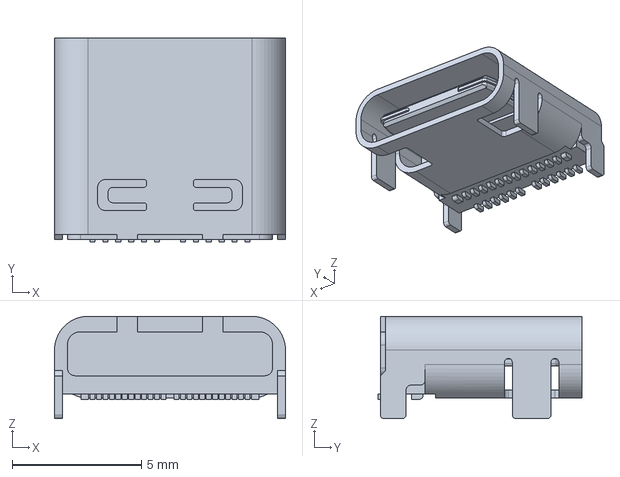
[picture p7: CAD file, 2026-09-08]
gpio-breakout-a2-b225/3dmodels/Molex_1054500101_official.stp
8.94 x 7.90 x 3.96 mm

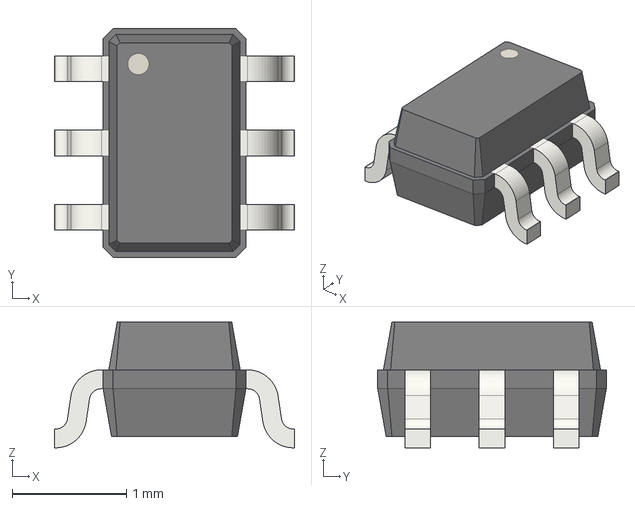
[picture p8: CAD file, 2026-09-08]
gpio-breakout-a2-b225/3dmodels/standard/SOT-363_SC-70-6.step
2.10 x 2.00 x 1.10 mm

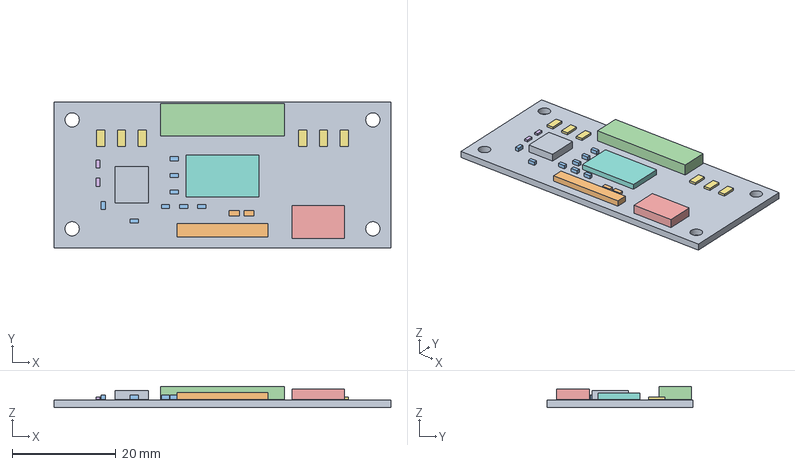
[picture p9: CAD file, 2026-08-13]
variants/koyomi-lvds-hat-rgb-compact-r2.3-routed/mechanical/print-models/koyomi-rgb-compact-r2.3-print-mockup.step
65.0 x 28.2 x 4.09 mm

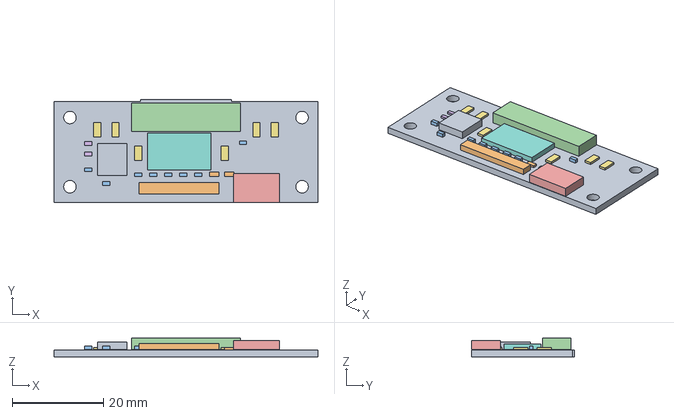
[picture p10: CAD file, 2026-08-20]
variants/koyomi-lvds-hat-rgb-compact-r2.7-30pct-floorplan/mechanical/print-models/koyomi-rgb-compact-r2.7-print-mockup.step
58.0 x 22.7 x 4.09 mm

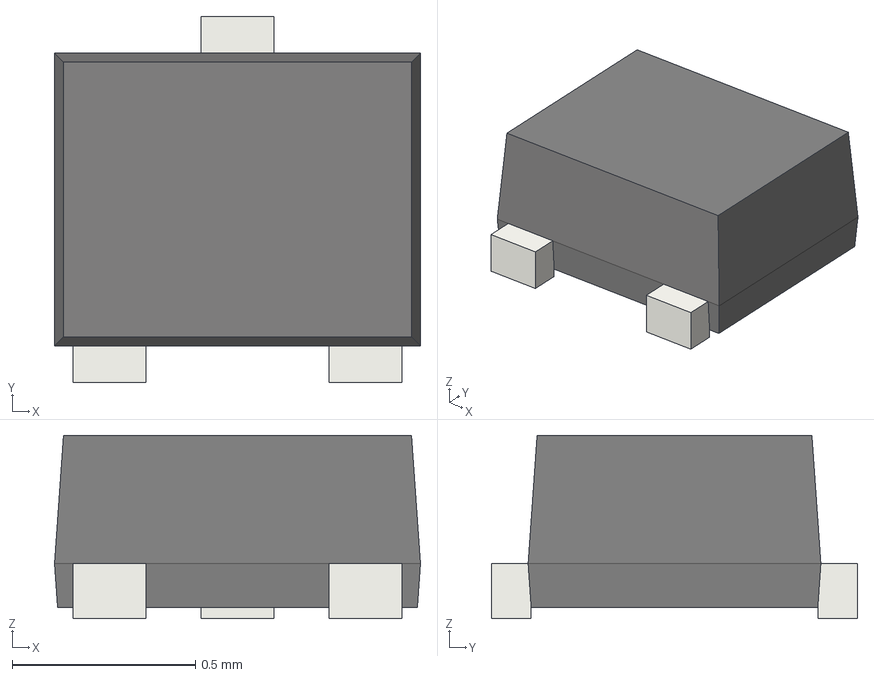
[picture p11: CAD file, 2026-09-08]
gpio-breakout-a2-b225/3dmodels/standard/Texas_DRT-3.step
1.00 x 1.00 x 0.5 mm

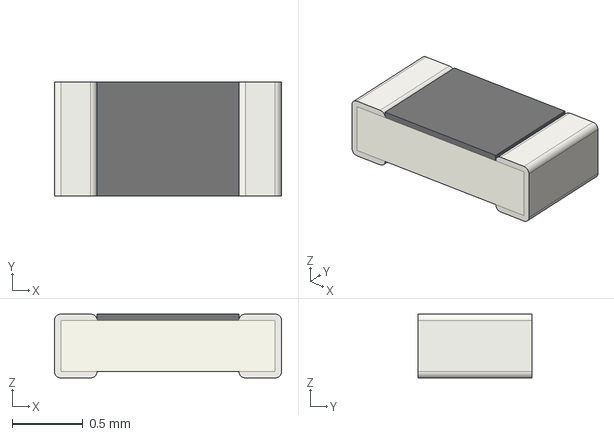
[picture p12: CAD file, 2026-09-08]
gpio-breakout-a2-b225/3dmodels/standard/R_0603_1608Metric.step
1.60 x 0.8 x 0.45 mm

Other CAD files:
variants/koyomi-lvds-hat-rgb-compact-r2.3-routed/mechanical/print-models/koyomi-rgb-compact-r2.3-print-mockup.stl
variants/koyomi-lvds-hat-rgb-compact-r2.7-30pct-floorplan/mechanical/print-models/koyomi-rgb-compact-r2.7-print-mockup.stl

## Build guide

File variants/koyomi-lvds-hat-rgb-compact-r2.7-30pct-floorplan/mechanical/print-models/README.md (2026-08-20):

# Koyomi RGB compact r2.7 print model

This bundle is generated from the single-side-assembly R2.7 compact LCD
controller floorplan in
`variants/koyomi-lvds-hat-rgb-compact-r2.7-30pct-floorplan/`.

Use `koyomi-rgb-compact-r2.7-print-mockup.stl` at **100% scale in
millimetres**. The matching STEP is provided for CAD collision checks.

The file includes:

- the exact 58.0 x 22.2 mm base outline, including the 20.0 x 0.5 mm JFFC1
  support tab and four mounting holes;
- outward-facing system FFC `JFFC1`;
- outward-facing panel micro-coax connector `J2`;
- outward-facing backlight FFC `JBL1`;
- all currently fitted ICs, resistor arrays, capacitors, and filters.

Detailed vendor models are converted to closed external occupancy envelopes.
This makes the STL deterministic and printable, while deliberately sacrificing
cosmetic component detail. FL1 and FL2 use conservative 2.0 x 1.0 x 0.5 mm
proxies because their source STEP file is missing from the project.

Regenerate with:

`/Applications/FreeCAD.app/Contents/MacOS/FreeCAD -c variants/koyomi-lvds-hat-rgb-compact-r2.7-30pct-floorplan/scripts/generate_print_model.py`

This is a mechanical floorplan gauge, not a fabrication release. The current
board has 0 geometric DRC violations but retains 138 intentional unconnected
items until native routing is complete.

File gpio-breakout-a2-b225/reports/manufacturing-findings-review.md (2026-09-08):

# GPIO A2 manufacturing review — 2026-09-09

The user selected **low-power USB2 bench use**. Retain F2 at 0.5 A; this is not authorization to draw the combined board's 1.5 A fuse rating from a normal USB2 host. Full downstream USB-A loading is outside this adapter's intended scope. This review does not release the board for manufacture or qualify a safe assembled load.

## Confirmed repair

J1's 40 signal pads and two SMT mounting pads lacked F.Paste. The native board now includes paste on all 42 pads, and the incorrect Hirose description is corrected to Samtec. The local library is repaired too. The board's copper, numbered pads, traces, vias, and other footprint geometry match the published pre-repair source. Native DRC has zero errors, zero unconnected items and six existing library warnings. The schematic was not changed.

The local footprint library was rebuilt with KiCad's native serializer from the native IPC snapshot because the available older library loader cannot read the previous experimental format. All 42 local pad positions/sizes/numbers, nine line segments, and the existing nominal envelope model were carried into the new library. The board itself remains in its existing native version and was edited through that version's API. The nominal model still cannot qualify latch or cable fit.

Samtec's [Rev E footprint drawing, figures 1 and 3](https://suddendocs.samtec.com/prints/zf5s-xx-xx-xx-wt-xx-footprint.pdf) uses matching copper/paste apertures: 0.30 by 1.60 mm contacts and 2.24 by 3.12 mm mounting pads. It specifies a 0.15 mm stencil, whereas [product specification section 6.3](https://suddendocs.samtec.com/productspecs/zf5s.pdf) recommends 0.13 mm. Reconcile that process discrepancy with the assembler before releasing the stencil; do not state that both documents specify 0.13 mm.

## Assessment of the eight findings

| Finding | Assessment and disposition |
| --- | --- |
| 1. Missing paste | Confirmed and repaired on GPIO A2 board and local library. The original library is also present in A2, B2.25, B2.27 and C1 checkouts; those board instances and libraries need the same repair in their own active work. They were not modified here. |
| 2. F2 and downstream load | Valid power-budget concern. Retain 0.5 A for the user's bench scope. Hold current is not a regulated current ceiling, and ambient temperature affects it. At an assumed 0.75 ohm resistance, 0.5 A causes 0.375 V drop; actual downstream voltage also depends on source voltage, resistance, cable and load. A downstream 1.5 A fuse does not grant a USB host power allowance. [USB-IF](https://compliance.usb.org/index.asp?Format=Standard&UpdateFile=Policies) limits a standard USB2 downstream port's peripheral load to 500 mA; configuration and hub budgeting still matter. |
| 3. Narrow power routes | Substantially confirmed: most power segments are 0.20 mm; USB_VBUS also contains 0.25 mm segments. LCD 5 V and 3.3 V paths use In2.Cu. Correction: the saved stack specifies 35 micrometre copper on every copper layer; 15.2 micrometre inner copper belongs to the intended JLC profile, not the saved board. A single width-to-current number does not qualify these paths. Widen principal rail runs, retain only necessary short fanouts, and recalculate voltage drop/thermal rise for the actual stack and bench load. Not changed by this paste-only repair. |
| 4. DPI source termination | No source arrays on this adapter. Source-side resistor options are a sensible layout improvement for the 22 driven DPI nets (18 RGB, clock, HSYNC, VSYNC, enable). Six isolated four-resistor arrays would cover them with two unused channels. Receiver-side 47 ohm arrays do not provide source termination for the upstream cable. Final values depend on driver impedance and channel behavior; zero-ohm options alone do not terminate the line. Not added or qualified in this repair. |
| 5. USB B-contact routes | Existing native path audit gives A+ 22.441 mm, A- 21.139 mm, B+ 28.090 mm, B- 29.885 mm; B paths use two vias. Thus B-A excess is about 5.65 mm and 8.75 mm. These endpoint-length differences are not the branch-point-to-unused-contact stub lengths, and do not establish a 480 Mb/s pass/fail limit. Measure the actual branches and qualify the channel. A 16-contact receptacle still normally exposes A6/A7 and B6/B7; a better footprint may shorten joins but does not automatically eliminate them. Connector replacement not made. |
| 6. Stackup | Confirmed open release blocker: native dielectric layers remain 0.48/0.48/0.48 mm, inconsistent with the intended JLC04161H-7628 calculation. No verified 90 ohm claim. Prior native setter and GUI access failures remain unresolved; no text-based native-source rewrite was substituted. |
| 7. Inrush | Confirmed system concern. C1's saved native netlist has 120.2 microfarad directly on its fused VBUS rail before counting further loads. Fuses and an ideal diode do not establish controlled inrush. [TI explains that LM66100 does not have inrush-current protection](https://e2e.ti.com/support/power-management-group/power-management/f/power-management-forum/869783/lm66100-lm66100-output-capacitance). Bench-only steady-state use does not remove plug-in charging. Review the actual power tree and capture inrush/host droop; add controlled charging if required. No scope measurement was performed. |
| 8. Wrong description | Confirmed and repaired on GPIO A2's embedded and library footprint. |

These findings do not demonstrate a pin-order error. They do establish unresolved assembly, power and signal-integrity work. Items 1 and 8 are repaired here; the remaining layout and qualification work is not represented as complete. No Gerber, drill, BOM, CPL, or fabrication package was generated or uploaded.

## Evidence

`j1-paste-repair.json` binds the pre/post native sources and preservation checks. `j1-library-repair.json` checks the serialized library. `manufacturing-findings-native.json` preserves the initial native paste, route and stackup evidence. `j1-paste-drc.json` is the post-repair DRC report. Earlier reports remain historical and retain their earlier source hashes; the manufacturing-findings artifact manifest identifies this revision.

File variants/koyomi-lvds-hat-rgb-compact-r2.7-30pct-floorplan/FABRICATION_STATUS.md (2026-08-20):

# R2.7 fabrication status

Updated: 2026-08-20

R2.7 is **fabrication-ready as a prototype**. The Gerber, drill, BOM, CPL,
STEP, render, and checksum package is
`../../fab/r2.7-compact-rgb-production-jlc-candidate/`.

## Release gates

- Native KiCad errors-only DRC: **0 violations, 0 unconnected pads**.
- Native KiCad all-severity DRC: 13 inherited footprint-library mismatch
  warnings, 0 unconnected pads, and no electrical/clearance errors.
- Errors-only schematic ERC: **0 errors, 0 warnings**.
- Routed board interface audit: **PASS** for all eleven named cross-connector
  nets.
- System interconnect gate:
  `python3 scripts/check_interconnect_release.py --board lcd`: **PASS**.
- Exact connector X/Y, rotation, F.Cu side, assigned edge, and outward-opening
  audit for `JFFC1`, `J2`, and `JBL1`: **PASS**.
- Fitted assembly: **23 top, 0 bottom**.
- Stack: four copper layers; minimum finished drill in the package: 0.20 mm.
- Package checksum manifest: generated and self-consistent.

The reproducible release command is:

```sh
python3 scripts/build_r2_7_jlc_candidate.py
```

from the repository root. The builder runs fail-closed and invokes the
external LCD interconnect gate before producing any output.

## Mechanical and visual evidence

- Actual outline area: 1297.6 mm², 29.33% below R2.6.
- Print mock-up validation: 58.0000 × 22.7000 × 4.0950 mm, 896 facets.
- Fresh actual KiCad top, bottom, side, and perspective renders were generated
  from the released PCB and reviewed. The top face contains all fitted parts,
  the bottom face contains none, and all three cable openings face outward.
- Render hashes are recorded in `reports/verification.md` and the fabrication
  package `SHA256SUMS` file.

## PCBA procurement boundary

The PCB is ready to fabricate, but JLCPCB cannot assemble every line directly
from warehouse stock as of 2026-08-20:

- `J2`, I-PEX `20374-R30E-31`, `C5311655`: stock 0; pre-order minimum 442.
- `FL1`/`FL2`, Murata `DLP2ADN121HL4L`, `C710576`: stock 0; consignment
  minimum 23.

Keep these exact BOM identities unless a new revision performs a datasheet,
footprint, pin-order, and signal-integrity review. `J2` mates with the panel
cable, and the filters sit directly in the LVDS path. Fabrication may proceed
without assembly, or PCBA may proceed after pre-order/consignment is received;
do not mark the two placements as silently substituted.

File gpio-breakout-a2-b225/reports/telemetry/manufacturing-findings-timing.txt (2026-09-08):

    5.069 s  verify-paste-repair-against-published-board
    3.482 s  diagnose-saved-footprint-comparison
    3.473 s  verify-j1-paste-across-native-sessions
    3.380 s  repair-j1-paste-verified-normalization
    3.030 s  inspect-manufacturing-findings
    2.855 s  inspect-manufacturing-findings-corrected-report
    2.594 s  verify-paste-repair-drc
    2.067 s  verify-paste-repair-drc-native-runtime
    1.837 s  diagnose-j1-native-roundtrip
    1.803 s  restore-j1-paste-native-corrected-wrapper
    1.593 s  restore-j1-paste-native
    0.348 s  repair-samtec-native-library-layer-set
    0.289 s  discover-native-footprint-export
    0.287 s  probe-native-library-parser
    0.221 s  serialize-samtec-to-isolated-library
    0.210 s  repair-samtec-native-library
    0.183 s  repair-samtec-native-library-fields
    0.131 s  verify-shared-library-and-c1-power-evidence
    0.038 s  review-bench-scope-release-gate
   32.890 s  measured phases
  972.554 s  intent-to-finish
  939.664 s  unmeasured coordination/analysis
identified: 2026-09-08T18:35:53.138+00:00
finished:   2026-09-08T18:52:05.681+00:00

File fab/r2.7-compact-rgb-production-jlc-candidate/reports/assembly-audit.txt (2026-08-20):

fitted placements: 23
top placements: 23
bottom placements: 0
assembly: single-sided Economic PCBA
copper stack: four layers
minimum via drill: 0.20 mm (fine-hole quote required)
H1-H4 and JP1-JP2: excluded from BOM/CPL
J2: C5311655; JBL1: C88360; JFFC1: C596805
sourcing: J2 C5311655 stock 0/pre-order min 442; FL1-FL2 C710576 stock 0/consign min 23 (checked 2026-08-20)
upload: Confirm Production File must be enabled

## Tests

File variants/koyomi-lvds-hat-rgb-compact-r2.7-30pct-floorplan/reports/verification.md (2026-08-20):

# Koyomi RGB compact R2.7 production verification

Date: 2026-08-20

## Mechanical result

- Source revision: R2.6 production candidate.
- R2.6 outline: 65.0 × 28.25 mm = 1836.25 mm².
- R2.7 base rectangle: 58.0 × 22.2 mm = 1287.6 mm².
- JFFC1 support tab: 20.0 × 0.5 mm = 10.0 mm².
- Actual R2.7 area: 1297.6 mm²; area reduction: 29.33%.
- Fitted parts: 23 front, 0 back.
- Mechanical/configuration footprints: H1–H4 and JP1–JP2 remain front-side
  bare features and are excluded from the fitted count.

## Edge connector orientation and interface

- Hirose's FH41 drawing places the cable opening opposite the 40 signal solder
  pads. At `JFFC1` rotation 180°, that opening faces the top `Edge.Cuts` tab.
- `J2` and `JBL1` open toward the bottom `Edge.Cuts` boundary.
- The B2.2 carrier-to-LCD audit rechecked contacts 1 through 40 after the
  rotation: all 40 pad numbers and assigned nets match the straight-through
  interface contract.
- The routed-interface audit passes all eleven named cross-connector nets,
  including `PANEL_ID0`, `PANEL_ID1`, `LCD_INS`, `EN`, and `PWM`.
- System, panel, and backlight connector identities are unchanged.

## Fresh KiCad checks

Checks use KiCad 10.99 nightly build `10.99.0-2630-ge98e17ed18`.

- PCB error-level violations: **0**.
- Unconnected pads: **0**.
- All-severity PCB findings: 13 inherited footprint-library mismatch warnings.
- Schematic ERC errors: **0**.
- DRC exclusions: **0**.
- External interconnect release gate: **PASS**.
- Edge-connector placement/orientation audit: **PASS**.
- Assembly audit: **23 top, 0 bottom**.

## Fresh KiCad render review

- `renders/top.png`: `fa46687dbbab8be16c698c153922f007af346c0a96db5a3edfbafe8346d8e1c5`
- `renders/bottom.png`: `6989b7be569368340e5461c2892fd35657ac89aad850ba26fdfbee5cefa69447`
- `renders/side.png`: `cfb10fd0ab40f05f77e22e5bbb01235e2911529792e345d51e8eef273db27f71`
- `renders/perspective.png`: `36f078f9469b306985c4ce3793d2cada49ba6e0b9e87c831101d5a005ab455e4`

The top render confirms that every fitted component is on F.Cu and all three
cable entries face their documented physical edges. The bottom render is free
of fitted parts. The side view confirms a single-sided assembly envelope.

## Release package

`scripts/build_r2_7_jlc_candidate.py` creates the checksum-locked package under
`fab/r2.7-compact-rgb-production-jlc-candidate/`. The PCB is approved for
prototype fabrication. PCBA checkout remains conditional on sourcing the two
zero-stock BOM identities documented in `FABRICATION_STATUS.md`.

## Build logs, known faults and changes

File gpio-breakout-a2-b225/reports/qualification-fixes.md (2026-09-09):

# GPIO A2 qualification corrections — 2026-09-09

The desktop design corrections are implemented. **This is not a fabrication
release or a record of completed hardware qualification.** Scope remains
low-power USB2 bench use with the user-selected Combined peripheral C1.

## Final sources and checks

- PCB SHA-256: `fc25e04aed25fc0094d64c32bc30104b626fe1165ffbb7e90a8c57916ff2e60d`.
- Schematic SHA-256: `318696ff14d9f45b238c8337d1508b61577e4c56837971118e5ead9886f4fc65`.
- Native DRC: **0 errors, 0 opens, 13 library snapshot warnings**.
- Native ERC: **0 active errors, 29 warnings**: 25 library snapshot differences
  and four intentionally unused Pi GPIO labels. The existing exact TI-documented
  ST-to-ground exclusion is retained; no electrical-rule matrix was weakened.
- Independent XML/native pad comparison: all **193 numbered pads** and all
  **40 FFC functions** match. J1 retains solder paste on all 42 pads.
- 27 unique footprints; 1,908 tracks and 124 vias. Nine parts were added.
- Native preservation comparison retains J1/J2/J3 geometry, all original
  component geometries except the intentionally moved bypass C1, and all 406
  original tracks outside the modified display/power/USB nets.
- The previously corrected JLC04161H-7628 construction is unchanged: outer
  copper 35 µm, inner 15.2 µm, outer dielectrics 0.2104 mm/Er 4.4, core
  1.065 mm/Er 4.6. New startup power routes have another 80 widened segments,
  up to 0.50 mm where clearance permits; three screened segments remain narrower.

Authoritative reports: [interface](qualification-interface.json),
[preservation](qualification-fixes-preservation.json),
[DRC](qualification-fixes-drc.json), [ERC](qualification-fixes-erc.json),
[native snapshot](qualification-native-snapshot.json),
[schematic XML](qualification-netlist.xml).

## USB B-contact routing

B6/B7 planar junction-to-contact branches are now **1.588/4.312 mm**, formerly
6.678/9.776 mm. The main 0.2774 mm / 0.20 mm pair is preserved. B6 stays on
F.Cu; B7 retains two through-vias and an In2.Cu segment. A-contact planar skew
is 1.302 mm; B-contact planar skew is 0.393 mm. **The B pair has unequal via
counts (0 versus 2), so planar skew alone is not electrical delay matching.**

At the saved F-to-In2 centre separation of 1.3157 mm, the two transitions add
about 2.6314 mm of vertical conductor on B7. Its full geometric branch is about
6.944 mm; this is not a claim that the whole branch meets TI's 200 mil stub
recommendation. The corresponding simple B-path length mismatch is about
3.024 mm before dielectric propagation and discontinuities are considered.

All 700 F.Cu-to-In1.Cu and 25 In2.Cu-to-B.Cu ground-reference samples pass
outside measured antipads. Return vias are 1.768 and 2.035 mm from the two data
vias. Coplanar ground remains interrupted at breakouts and bends. Thus the
routing is shorter, but uniform 90 ohm impedance and the assembled USB channel
remain unqualified. Test both plug orientations. [Native path audit](usb2-path-audit.json).

## Controlled USB startup

The USB supply path is now J3 → F2 0.5 A PTC → **U4 TPS22918DBVR/C131941** →
U1 LM66100 reverse blocker → FFC pins 1–4. U4 is before the existing reverse
blocker so its body path does not replace that protection. ON is tied to VIN;
QOD is unconnected. C3 is **10 nF C0G 50 V 5%, C76599** on CT. C4 adds 1 µF
on the switched rail. The LCD5V/3V3 links remain separate and default-open.

[TI's TPS22918 datasheet](https://www.ti.com/lit/ds/symlink/tps22918.pdf)
gives a typical 26.55 ms 10–90% rise at 5 V with this CT value. For the peer's
nominal 120.2 µF this implies about 18.1 mA mean capacitor charging current in
that interval, excluding operating load. It is not a guaranteed peak limit or
proof of USB host allocation compliance. Measure actual current, host droop,
reset/startup and externally powered peer behavior.

At 60°C the sampled positive copper path estimate is 0.0899 Ω. Including the
PTC's 0.75 Ω upper post-reflow value gives 84/210/420 mV at 100/250/500 mA,
**before** U4, U1, USB cable, FFC, contact, return and peer losses. F2 is not a
precision limiter. This update does not provide full downstream USB-A power.
[Power estimates and exclusions](power-path-qualification.json).

## Pi-side display provisions

RN1–RN6 are six isolated four-element 0603 arrays, initially **0 Ω**
(`4D03WGJ0000T5E`, C1952). Exactly 22 Pi outputs, GPIO0–21 (0/1 named
ID_SD/ID_SC), pass through one element each. Two unused elements remain NC.
The Pi header-to-resistor planar runs measure 3.066–10.872 mm. Total planar
header-to-FFC runs through the arrays measure 26.242–72.024 mm.

These are source-side tuning provisions, not qualified termination values.
The exact Pi, drive setting, panel and pixel clock still need confirmation.
Historical project settings suggest 83.6 MHz RGB666 1600×768, but are not
confirmed for this setup. Coordinate any nonzero source population with C1's
existing receiver-side 47 Ω arrays. Measure receiving setup/hold and ringing.
[DPI topology and path audit](dpi-qualification.json).

## C1 and mechanical status

C1 commit `00c6e73d` now enables paste on **all 42 J401 pads**. Its source-bound
preflight reports zero geometry errors, opens and schematic parity findings;
this closes the earlier missing-paste finding. The native connector read binds
PCB SHA-256 `1bbc9a6f8cb5cf28cb54341c03c1d5cdff20cfe000a83fd909f164c52de66f84`.
All 40 numbered functions still correspond to GPIO A2.
[C1 connector evidence](c1-paste-current.json). C1 was inspected, not edited.

Both ends specify Samtec ZF5S-40-01-T-WT-K-TR. Samtec lists FJH as the mating
family; the existing catalog candidate is FJH-40-R-03.00-4, 76.2 mm. Manufacturer
family compatibility does not prove installed contact-face orientation, length,
latch access or fold clearance. Verify these with the actual selected assembly.
Physical continuity is a TODO after cable selection, not the sole release
blocker. No custom harness or repinning is permitted.

[Native top](../renders/qualification-fixes-top.png) and
[USB-entry side](../renders/qualification-fixes-right.png) were inspected at the
final PCB hash. New components use standard package models. J1 remains a nominal
Samtec envelope and J2 has no selected stacking-socket model; neither proves fit.
J3's exact official Molex model and placement are unchanged. Its mouth overhang
is only 0.05 mm, requiring plug-shroud clearance in the intended installation.
[Native schematic preview](../renders/schematic/gpio_breakout.svg).

## Remaining qualification and artifact scope

Follow the [bench procedure](bench-qualification-plan.md) for the actual
host/display/peer/cable combination. Record measured USB startup and supply
behavior, both USB-C orientations, and display timing. Confirm the catalog
cable's installed geometry. These checks are not replaced by DRC or calculations.

The authoritative interconnect contract retains a manufacturing hold with these
current reasons. No fabrication files were generated and nothing was uploaded
to JLCPCB. Files named `qualification-route-pass`, `qualification-placement`,
`qualification-updated-netlist`, `qualification-board-import`, `startup-routing`,
`startup-width-qualification` and `usb2-short-joins` are intermediate revision
records; use final hashes/reports above for the current board. Earlier stackup
and USB reports are historical where their hashes differ.

All KiCad edits, failed retries, audits and renders are instrumented in the
`20260909T082142-4e01c546` telemetry run. These scripts are sequential revision
steps, not an idempotent whole-board generator; do not rerun the historical
netlist importer on the finished board. Native import duplicated three custom
footprints; their original geometries were restored and all 27 final references
and schematic paths were checked. Local symbol graphics and absolute pin
coordinates are handled separately in the final schematic cleanup.

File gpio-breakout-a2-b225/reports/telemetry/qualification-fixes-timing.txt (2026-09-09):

   95.612 s  route-startup-and-source-series-retry
   60.209 s  baseline-inspection-retry
   53.459 s  complete-startup-routing
    9.494 s  final-startup-routing
    5.419 s  repair-custom-import-and-startup-placement
    5.079 s  complete-startup-ground
    4.885 s  finish-schematic-layout
    4.876 s  qualification-top-review
    4.617 s  clear-passive-field-labels
    4.599 s  final-top-review
    4.503 s  finish-schematic-labels
    4.233 s  import-qualification-circuit
    3.738 s  native-symbol-and-usb-width
    3.641 s  current-c1-paste-and-array-definition
    3.234 s  bind-new-component-identities
    3.149 s  unrelated-copper-and-connector-preservation
    3.130 s  widen-new-startup-power
    2.888 s  finish-ground-labels-and-models
    2.494 s  shorten-usb-contact-joins
    2.458 s  final-source-drc
    2.422 s  short-usb-drc
    2.349 s  qualification-routing-drc
    2.002 s  route-startup-and-source-series
    1.832 s  qualification-finished-drc
    1.815 s  final-source-erc
    1.786 s  qualification-cleanup-drc
    1.778 s  short-usb-final-width-drc
    1.773 s  final-schematic-erc
    1.710 s  clear-last-startup-courtyards
    1.706 s  final-usb-channel-geometry
    1.702 s  final-usb-contact-audit
    1.696 s  qualification-new-circuit-erc
    1.681 s  add-startup-and-dpi-circuit-retry
    1.634 s  baseline-inspection-native-access
    1.584 s  archive-native-array-template
    1.581 s  final-native-geometry-snapshot
    1.578 s  add-startup-and-dpi-circuit
    1.561 s  inspect-schematic-layout
    1.549 s  locate-ground-island-retry
    1.518 s  final-interface-contract
    1.500 s  inspect-startup-courtyards
    1.491 s  inspect-exact-courtyard-boundaries
    1.303 s  final-usb-entry-view
    1.165 s  final-schematic-netlist
    0.596 s  final-schematic-netlist
    0.566 s  final-schematic-svg
    0.387 s  schematic-layout-preview
    0.381 s  schematic-readable-preview
    0.378 s  final-schematic-visual
    0.239 s  validate-corrected-symbol-library
    0.220 s  validate-native-symbol-library
    0.218 s  native-runtime-check
    0.212 s  native-symbol-export-options
    0.101 s  locate-ground-island
    0.094 s  independent-display-series-audit
    0.083 s  baseline-inspection
    0.078 s  final-evidence-binding
    0.060 s  updated-power-budget
    0.054 s  final-netlist-parity
    0.051 s  independent-pin-and-startup-audit
    0.037 s  final-interconnect-release-gate
    0.036 s  recorded-release-hold
    0.027 s  package-native-load-switch-symbol
    0.027 s  package-corrected-switch-symbol
  326.283 s  measured phases
 3374.349 s  intent-to-finish
 3048.066 s  unmeasured coordination/analysis
identified: 2026-09-09T01:21:42.688+00:00
finished:   2026-09-09T02:17:57.099+00:00

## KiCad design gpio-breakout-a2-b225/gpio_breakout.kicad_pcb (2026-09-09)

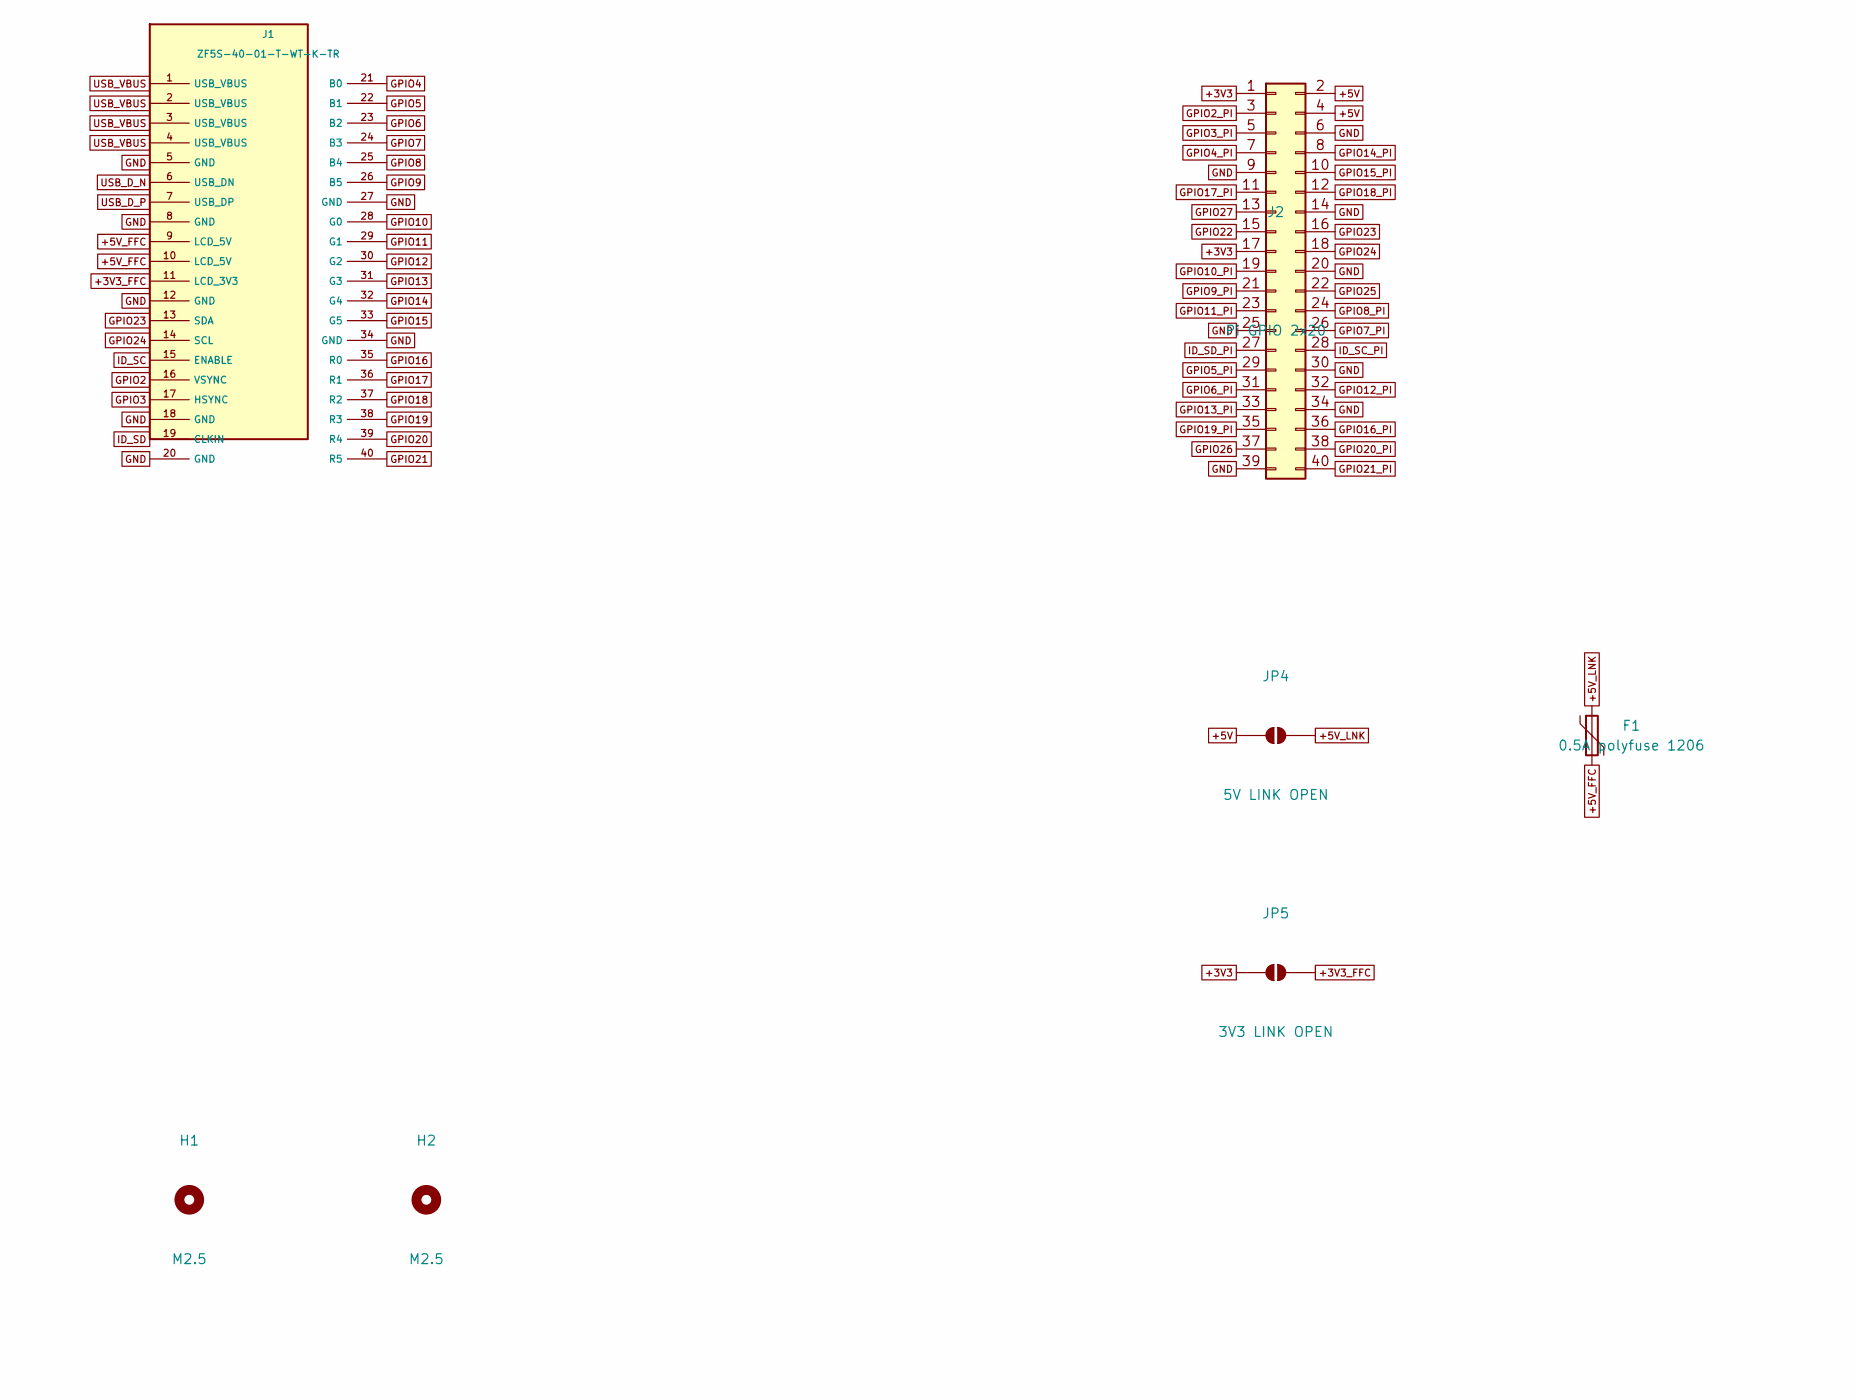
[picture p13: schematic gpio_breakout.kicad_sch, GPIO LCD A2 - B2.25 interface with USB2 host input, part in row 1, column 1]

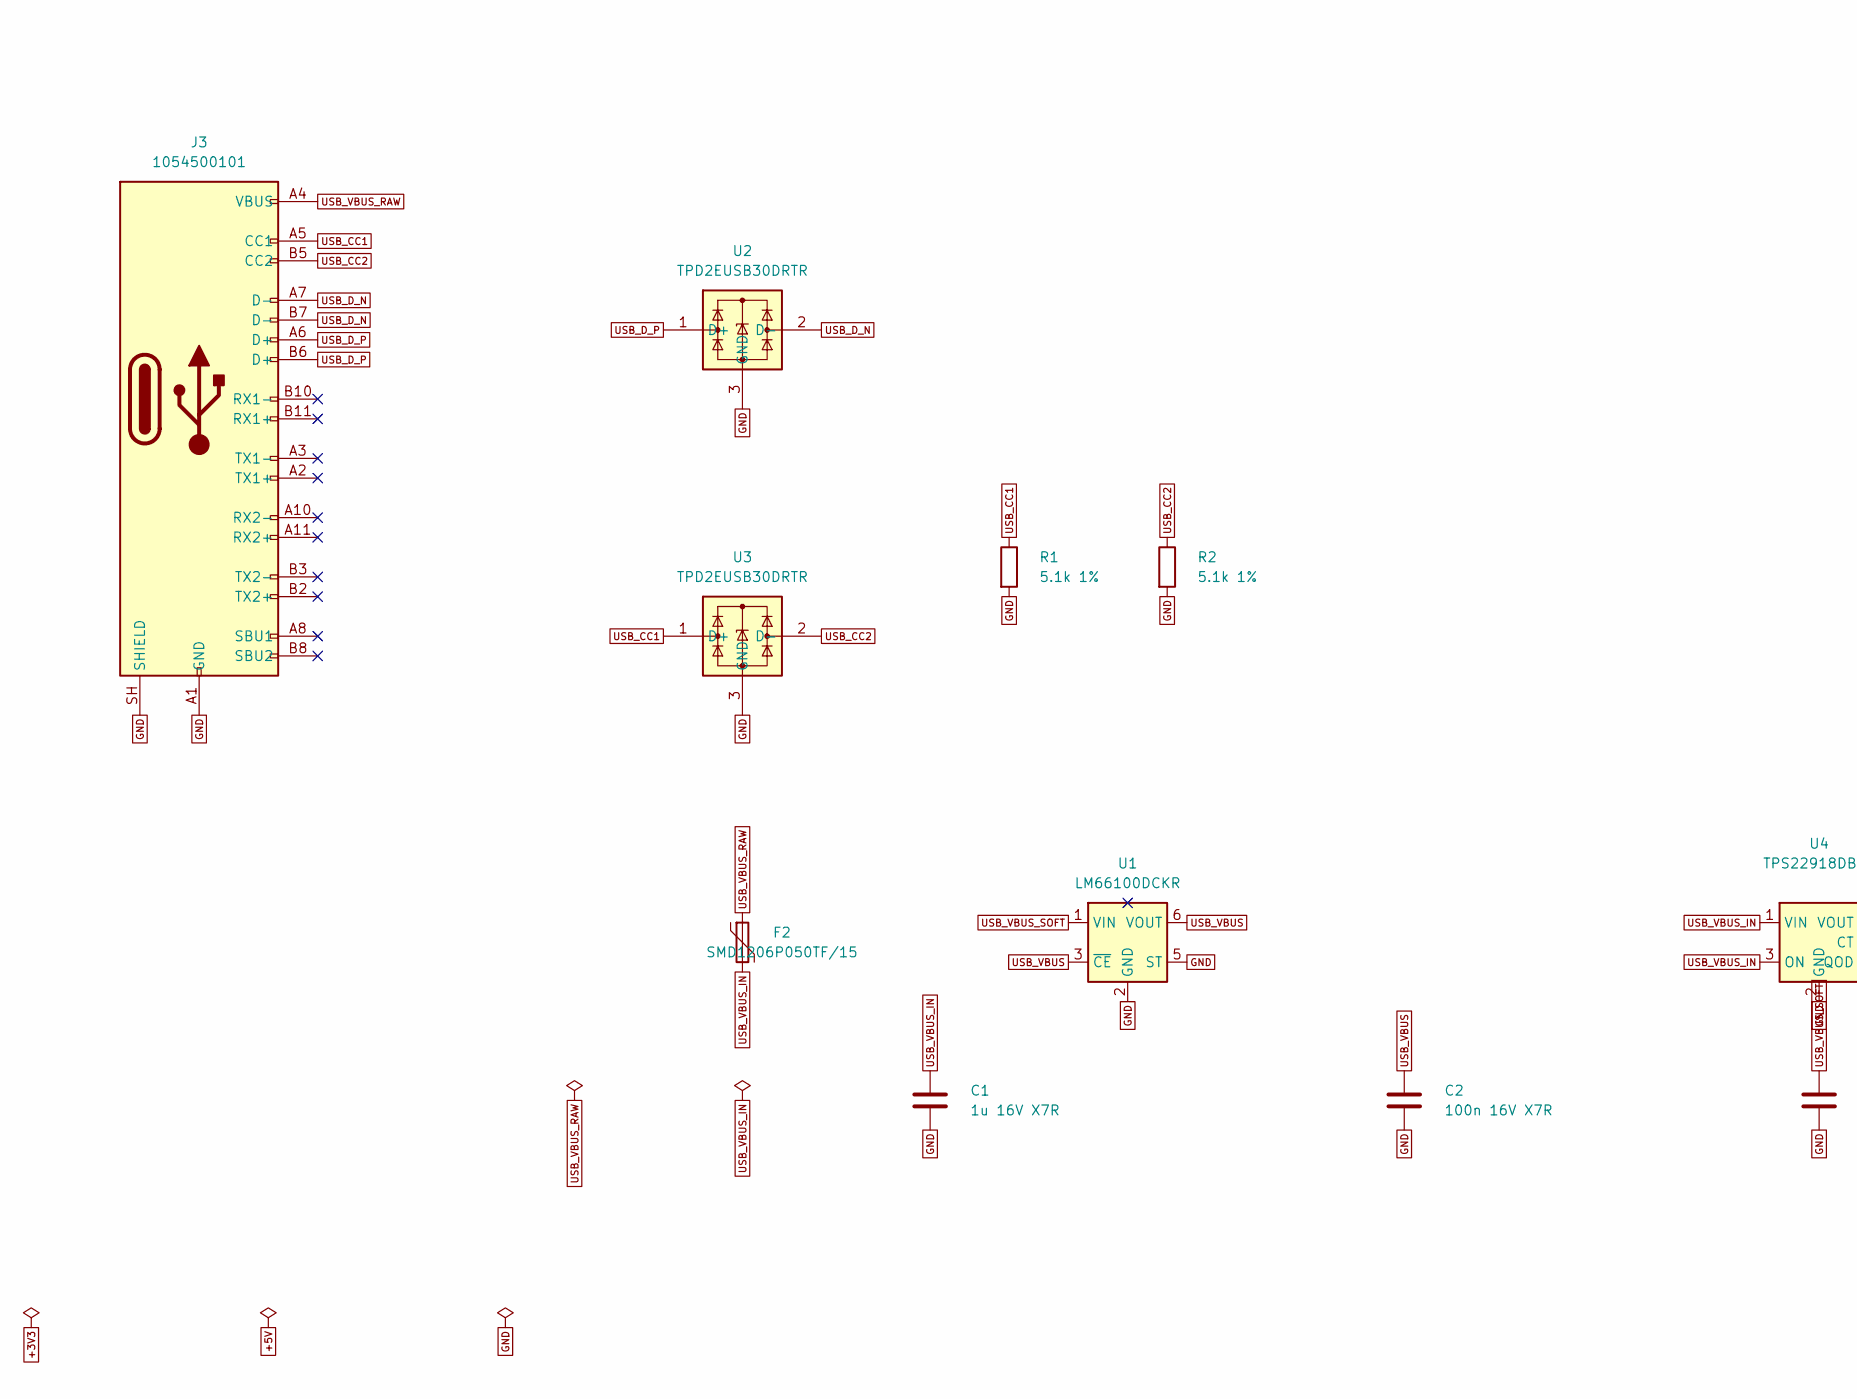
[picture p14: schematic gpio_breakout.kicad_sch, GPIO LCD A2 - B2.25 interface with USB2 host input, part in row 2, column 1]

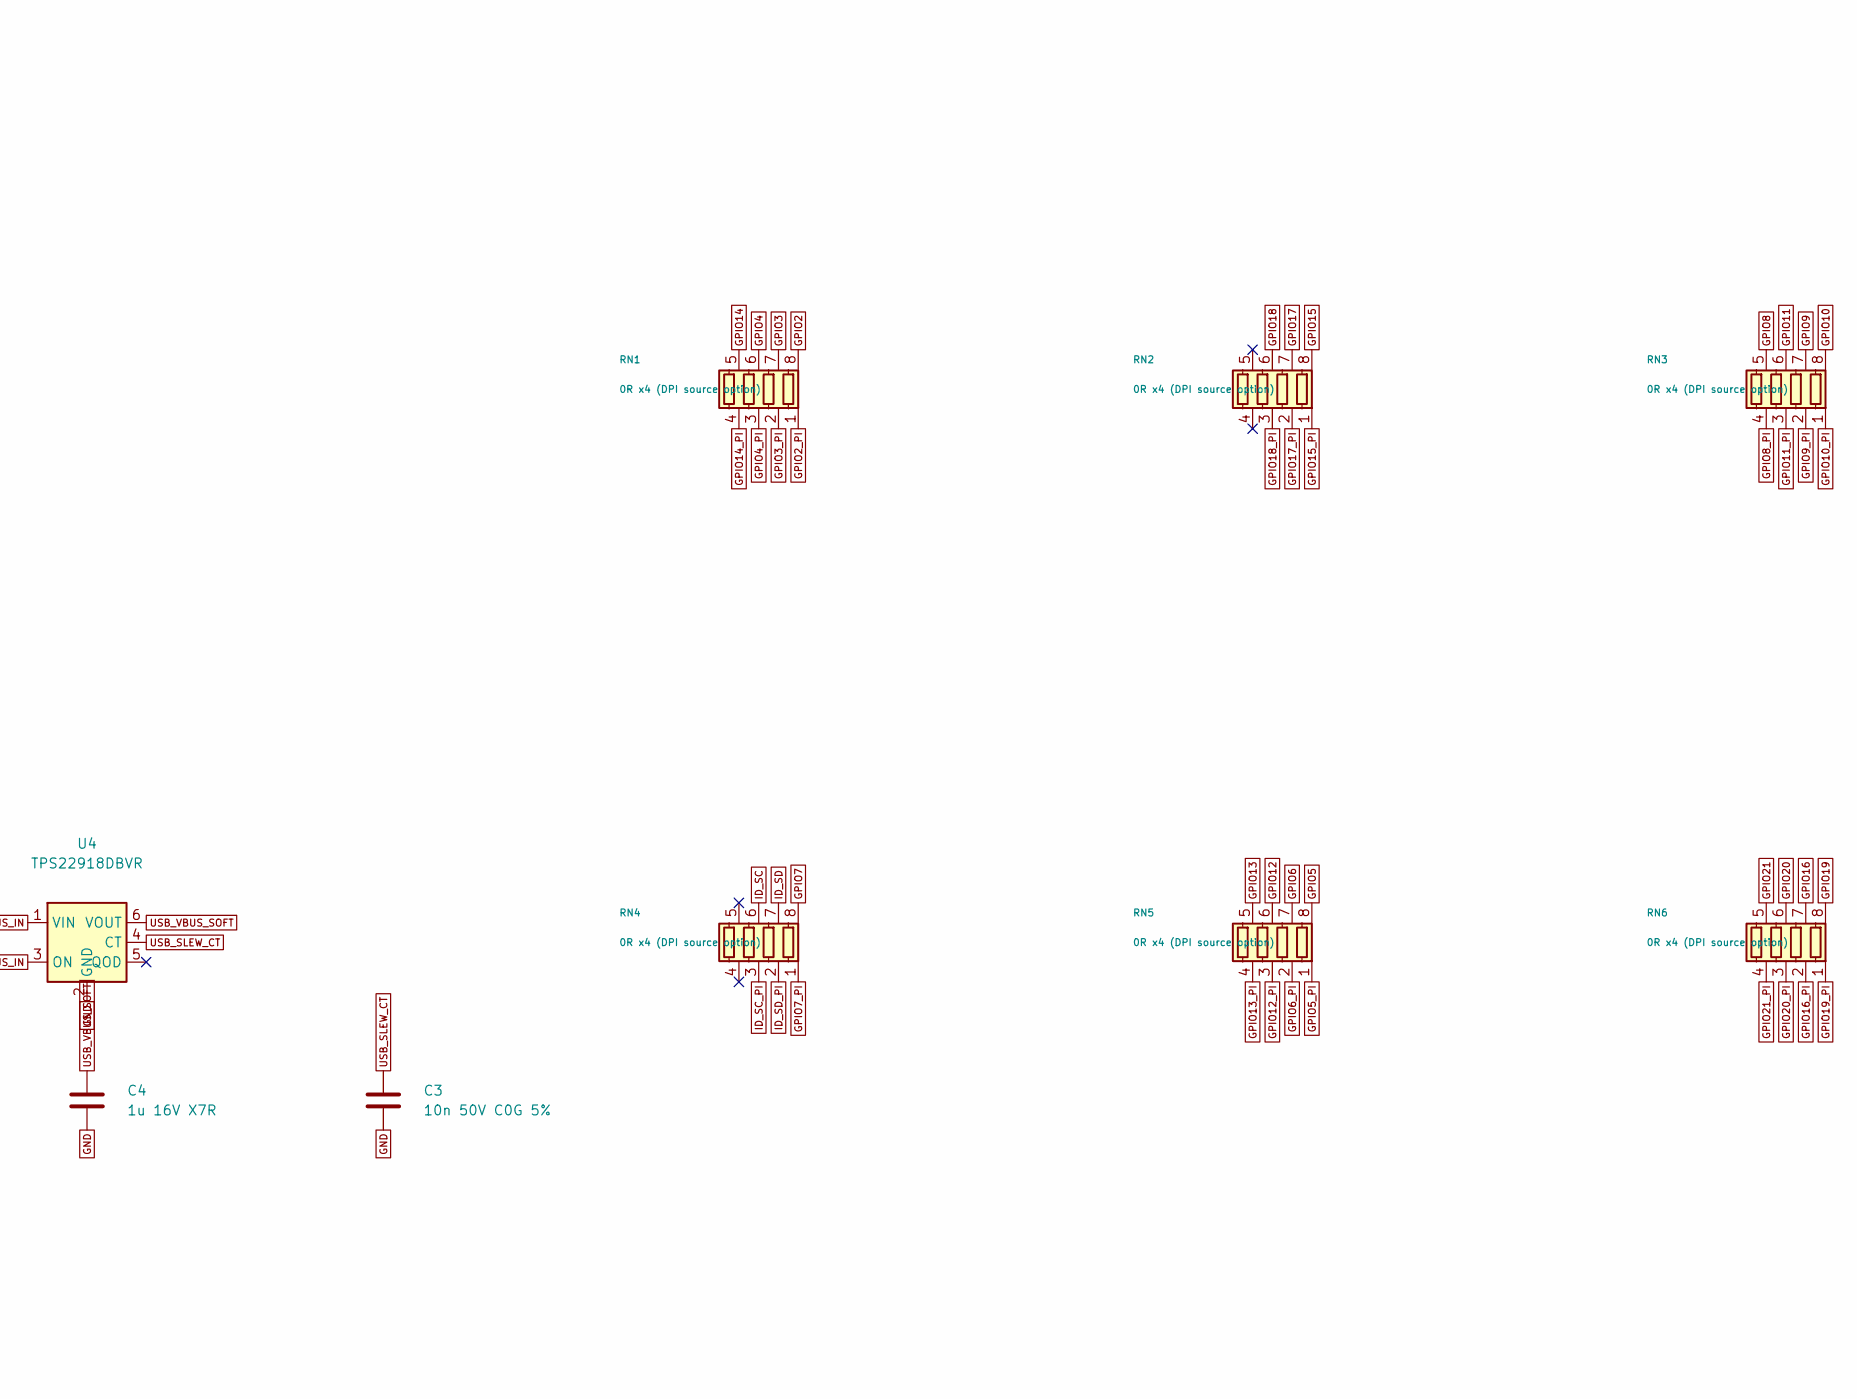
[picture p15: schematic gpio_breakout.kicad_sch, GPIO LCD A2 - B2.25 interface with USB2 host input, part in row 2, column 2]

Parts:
C1, C4: 1u 16V X7R; C_0603_1608Metric
C2: 100n 16V X7R; C_0603_1608Metric
C3: 10n 50V C0G 5%; C_0603_1608Metric; MPN C1608C0G1H103JT000N; LCSC C76599
F1: 0.5A polyfuse 1206; Fuse_1206_3216Metric
F2: SMD1206P050TF/15; Fuse_1206_3216Metric
H1, H2: M2.5; MountingHole_2.7mm_M2.5
J1: ZF5S-40-01-T-WT-K-TR; Samtec_ZF5S-40-01-T-WT_1x40_P0.50mm; LCSC C3169111
J2: Pi GPIO 2x20; PinHeader_2x20_P2.54mm_Vertical
J3: 1054500101; USB_C_Receptacle_Molex_105450-0101
JP4: 5V LINK OPEN; SolderJumper-2_P1.3mm_Open_RoundedPad1.0x1.5mm
JP5: 3V3 LINK OPEN; SolderJumper-2_P1.3mm_Open_RoundedPad1.0x1.5mm
R1, R2: 5.1k 1%; R_0603_1608Metric
RN1, RN2, RN3, RN4, RN5, RN6: 0R x4 (DPI source option); R_Array_Convex_4x0603; MPN 4D03WGJ0000T5E; LCSC C1952
TP4: GND; TestPoint_Pad_1.5x1.5mm
TP5: 3V3; TestPoint_Pad_1.5x1.5mm
U1: LM66100DCKR; SOT-363_SC-70-6
U2, U3: TPD2EUSB30DRTR; Texas_DRT-3
U4: TPS22918DBVR; SOT-23-6; MPN TPS22918DBVR; LCSC C131941

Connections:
+3V3: J2.1, J2.17, JP5.1 (A), TP5.1 (1_1)
+3V3_FFC: J1.11 (LCD_3V3), JP5.2 (B)
+5V: J2.2, J2.4, JP4.1 (A)
+5V_FFC: F1.2, J1.9 (LCD_5V), J1.10 (LCD_5V)
+5V_LNK: F1.1, JP4.2 (B)
GND: C1.2, C2.2, C3.2, C4.2, J1.5 (GND), J1.8 (GND), J1.12 (GND), J1.18 (GND), J1.20 (GND), J1.27 (GND), J1.34 (GND), J2.6, J2.9, J2.14, J2.20, J2.25, J2.30, J2.34, J2.39, J3.A1 (GND), J3.A12 (GND), J3.B1 (GND), J3.B12 (GND), J3.SH (SHIELD), R1.2, R2.2, TP4.1 (1_1), U1.2 (GND), U1.5 (ST), U2.3 (GND), U3.3 (GND), U4.2 (GND)
GPIO2: J1.16 (VSYNC), RN1.8 (R1.2)
GPIO2_PI: J2.3, RN1.1 (R1.1)
GPIO3: J1.17 (HSYNC), RN1.7 (R2.2)
GPIO3_PI: J2.5, RN1.2 (R2.1)
GPIO4: J1.21 (B0), RN1.6 (R3.2)
GPIO4_PI: J2.7, RN1.3 (R3.1)
GPIO5: J1.22 (B1), RN5.8 (R1.2)
GPIO5_PI: J2.29, RN5.1 (R1.1)
GPIO6: J1.23 (B2), RN5.7 (R2.2)
GPIO6_PI: J2.31, RN5.2 (R2.1)
GPIO7: J1.24 (B3), RN4.8 (R1.2)
GPIO7_PI: J2.26, RN4.1 (R1.1)
GPIO8: J1.25 (B4), RN3.5 (R4.2)
GPIO8_PI: J2.24, RN3.4 (R4.1)
GPIO9: J1.26 (B5), RN3.7 (R2.2)
GPIO9_PI: J2.21, RN3.2 (R2.1)
GPIO10: J1.28 (G0), RN3.8 (R1.2)
GPIO10_PI: J2.19, RN3.1 (R1.1)
GPIO11: J1.29 (G1), RN3.6 (R3.2)
GPIO11_PI: J2.23, RN3.3 (R3.1)
GPIO12: J1.30 (G2), RN5.6 (R3.2)
GPIO12_PI: J2.32, RN5.3 (R3.1)
GPIO13: J1.31 (G3), RN5.5 (R4.2)
GPIO13_PI: J2.33, RN5.4 (R4.1)
GPIO14: J1.32 (G4), RN1.5 (R4.2)
GPIO14_PI: J2.8, RN1.4 (R4.1)
GPIO15: J1.33 (G5), RN2.8 (R1.2)
GPIO15_PI: J2.10, RN2.1 (R1.1)
GPIO16: J1.35 (R0), RN6.7 (R2.2)
GPIO16_PI: J2.36, RN6.2 (R2.1)
GPIO17: J1.36 (R1), RN2.7 (R2.2)
GPIO17_PI: J2.11, RN2.2 (R2.1)
GPIO18: J1.37 (R2), RN2.6 (R3.2)
GPIO18_PI: J2.12, RN2.3 (R3.1)
GPIO19: J1.38 (R3), RN6.8 (R1.2)
GPIO19_PI: J2.35, RN6.1 (R1.1)
GPIO20: J1.39 (R4), RN6.6 (R3.2)
GPIO20_PI: J2.38, RN6.3 (R3.1)
GPIO21: J1.40 (R5), RN6.5 (R4.2)
GPIO21_PI: J2.40, RN6.4 (R4.1)
GPIO22: J2.15
GPIO23: J1.13 (SDA), J2.16
GPIO24: J1.14 (SCL), J2.18
GPIO25: J2.22
GPIO26: J2.37
GPIO27: J2.13
ID_SC: J1.15 (ENABLE), RN4.6 (R3.2)
ID_SC_PI: J2.28, RN4.3 (R3.1)
ID_SD: J1.19 (CLKIN), RN4.7 (R2.2)
ID_SD_PI: J2.27, RN4.2 (R2.1)
USB_CC1: J3.A5 (CC1), R1.1, U3.1 (D+)
USB_CC2: J3.B5 (CC2), R2.1, U3.2 (D-)
USB_D_N: J1.6 (USB_DN), J3.A7 (D-), J3.B7 (D-), U2.2 (D-)
USB_D_P: J1.7 (USB_DP), J3.A6 (D+), J3.B6 (D+), U2.1 (D+)
USB_SLEW_CT: C3.1, U4.4 (CT)
USB_VBUS: C2.1, J1.1 (USB_VBUS), J1.2 (USB_VBUS), J1.3 (USB_VBUS), J1.4 (USB_VBUS), U1.3 (~CE), U1.6 (VOUT)
USB_VBUS_IN: C1.1, F2.2, U4.1 (VIN), U4.3 (ON)
USB_VBUS_RAW: F2.1, J3.A4 (VBUS), J3.A9 (VBUS), J3.B4 (VBUS), J3.B9 (VBUS)
USB_VBUS_SOFT: C4.1, U1.1 (VIN), U4.6 (VOUT)

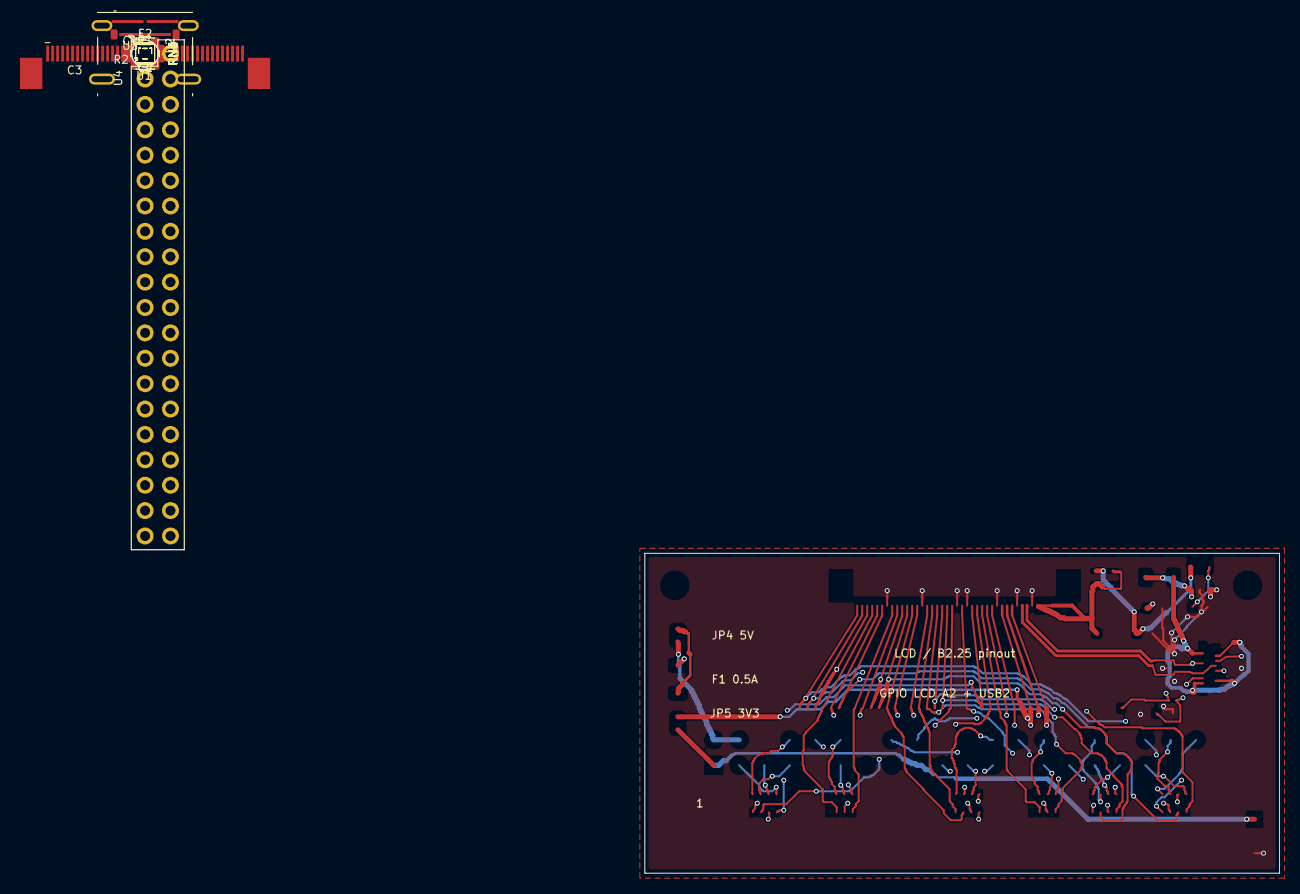
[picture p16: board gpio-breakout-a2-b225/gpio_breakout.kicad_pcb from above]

Board: 4 copper layers, 63.5 x 32.0 mm, 27 parts (0 on the bottom side), 61 nets.

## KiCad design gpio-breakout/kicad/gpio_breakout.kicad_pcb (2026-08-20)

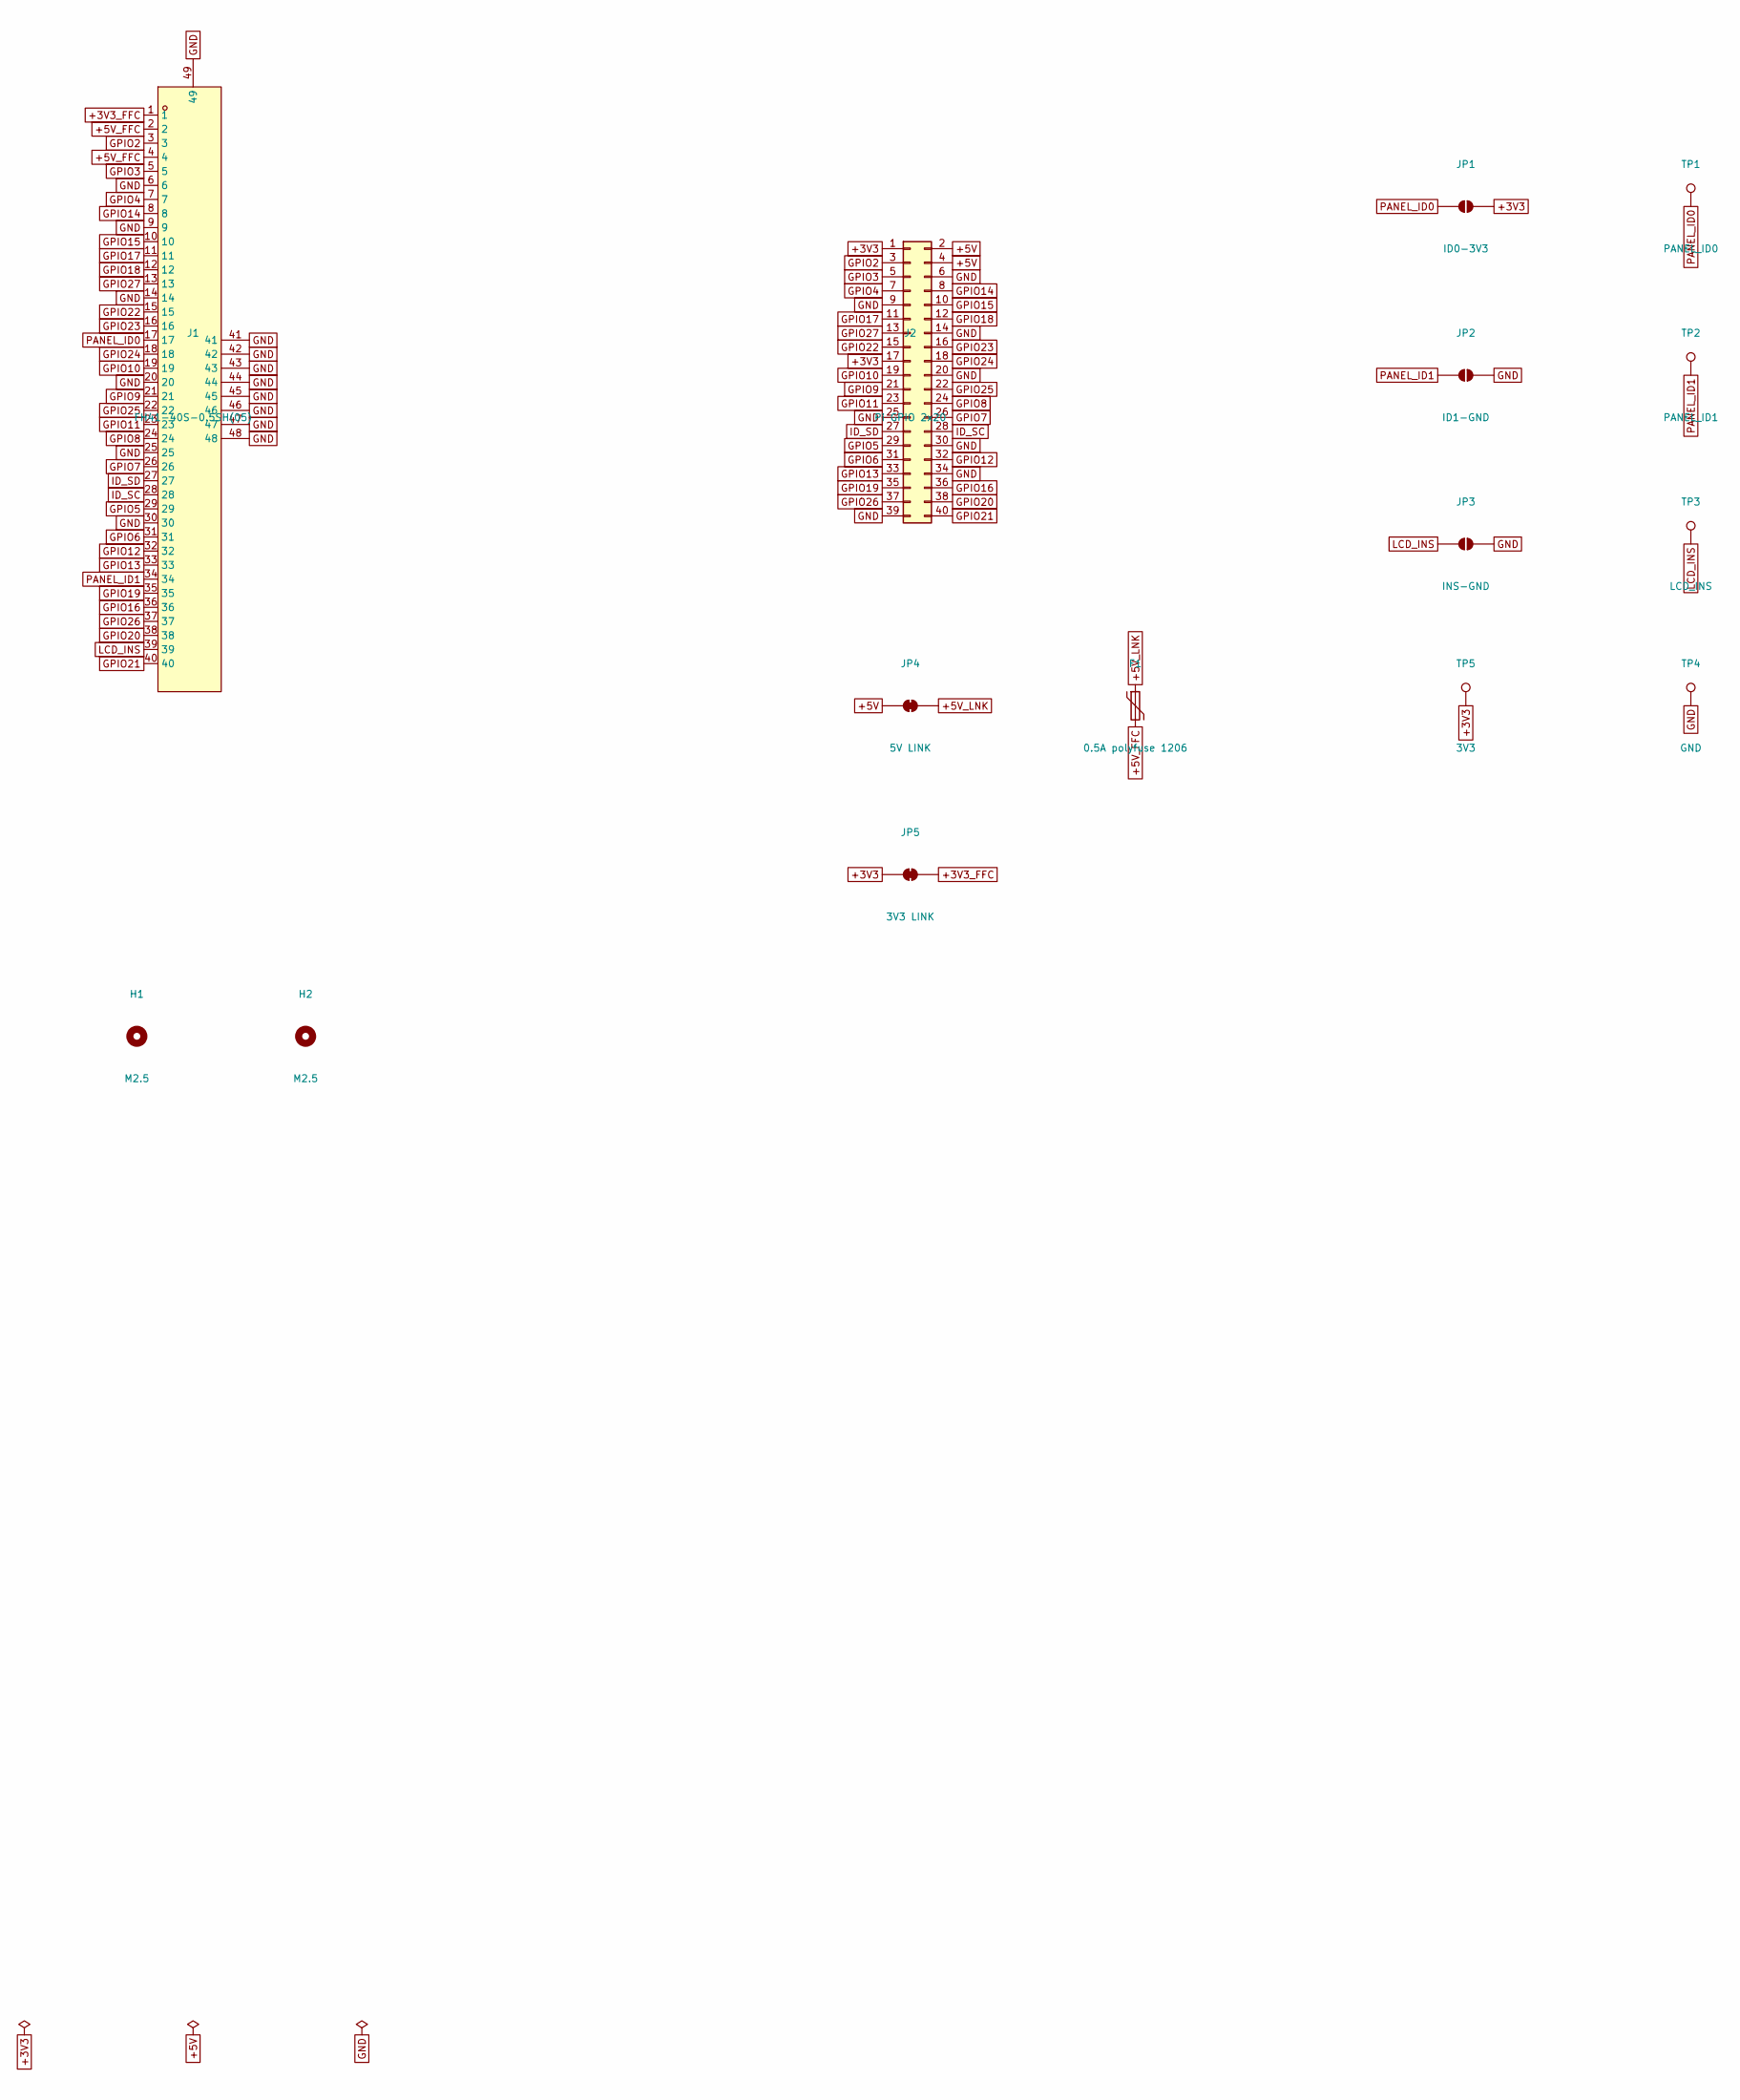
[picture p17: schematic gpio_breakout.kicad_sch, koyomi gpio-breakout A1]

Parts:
F1: 0.5A polyfuse 1206; Fuse_1206_3216Metric
H1, H2: M2.5; MountingHole_2.7mm_M2.5
J1: FH41-40S-0.5SH(05); FPC-SMD_FH41-40S-0.5SH; LCSC C596805
J2: Pi GPIO 2x20; PinHeader_2x20_P2.54mm_Vertical
JP1: ID0-3V3; SolderJumper-2_P1.3mm_Open_RoundedPad1.0x1.5mm
JP2: ID1-GND; SolderJumper-2_P1.3mm_Open_RoundedPad1.0x1.5mm
JP3: INS-GND; SolderJumper-2_P1.3mm_Open_RoundedPad1.0x1.5mm
JP4: 5V LINK; SolderJumper-2_P1.3mm_Bridged_RoundedPad1.0x1.5mm
JP5: 3V3 LINK; SolderJumper-2_P1.3mm_Bridged_RoundedPad1.0x1.5mm
TP1: PANEL_ID0; TestPoint_Pad_1.5x1.5mm
TP2: PANEL_ID1; TestPoint_Pad_1.5x1.5mm
TP3: LCD_INS; TestPoint_Pad_1.5x1.5mm
TP4: GND; TestPoint_Pad_1.5x1.5mm
TP5: 3V3; TestPoint_Pad_1.5x1.5mm

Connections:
+3V3: J2.1, J2.17, JP1.2 (B), JP5.1 (A), TP5.1
+3V3_FFC: J1.1, JP5.2 (B)
+5V: J2.2, J2.4, JP4.1 (A)
+5V_FFC: F1.2, J1.2, J1.4
+5V_LNK: F1.1, JP4.2 (B)
GND: J1.6, J1.9, J1.14, J1.20, J1.25, J1.30, J1.41, J1.42, J1.43, J1.44, J1.45, J1.46, J1.47, J1.48, J1.49, J1.50, J2.6, J2.9, J2.14, J2.20, J2.25, J2.30, J2.34, J2.39, JP2.2 (B), JP3.2 (B), TP4.1
GPIO2: J1.3, J2.3
GPIO3: J1.5, J2.5
GPIO4: J1.7, J2.7
GPIO5: J1.29, J2.29
GPIO6: J1.31, J2.31
GPIO7: J1.26, J2.26
GPIO8: J1.24, J2.24
GPIO9: J1.21, J2.21
GPIO10: J1.19, J2.19
GPIO11: J1.23, J2.23
GPIO12: J1.32, J2.32
GPIO13: J1.33, J2.33
GPIO14: J1.8, J2.8
GPIO15: J1.10, J2.10
GPIO16: J1.36, J2.36
GPIO17: J1.11, J2.11
GPIO18: J1.12, J2.12
GPIO19: J1.35, J2.35
GPIO20: J1.38, J2.38
GPIO21: J1.40, J2.40
GPIO22: J1.15, J2.15
GPIO23: J1.16, J2.16
GPIO24: J1.18, J2.18
GPIO25: J1.22, J2.22
GPIO26: J1.37, J2.37
GPIO27: J1.13, J2.13
ID_SC: J1.28, J2.28
ID_SD: J1.27, J2.27
LCD_INS: J1.39, JP3.1 (A), TP3.1
PANEL_ID0: J1.17, JP1.1 (A), TP1.1
PANEL_ID1: J1.34, JP2.1 (A), TP2.1

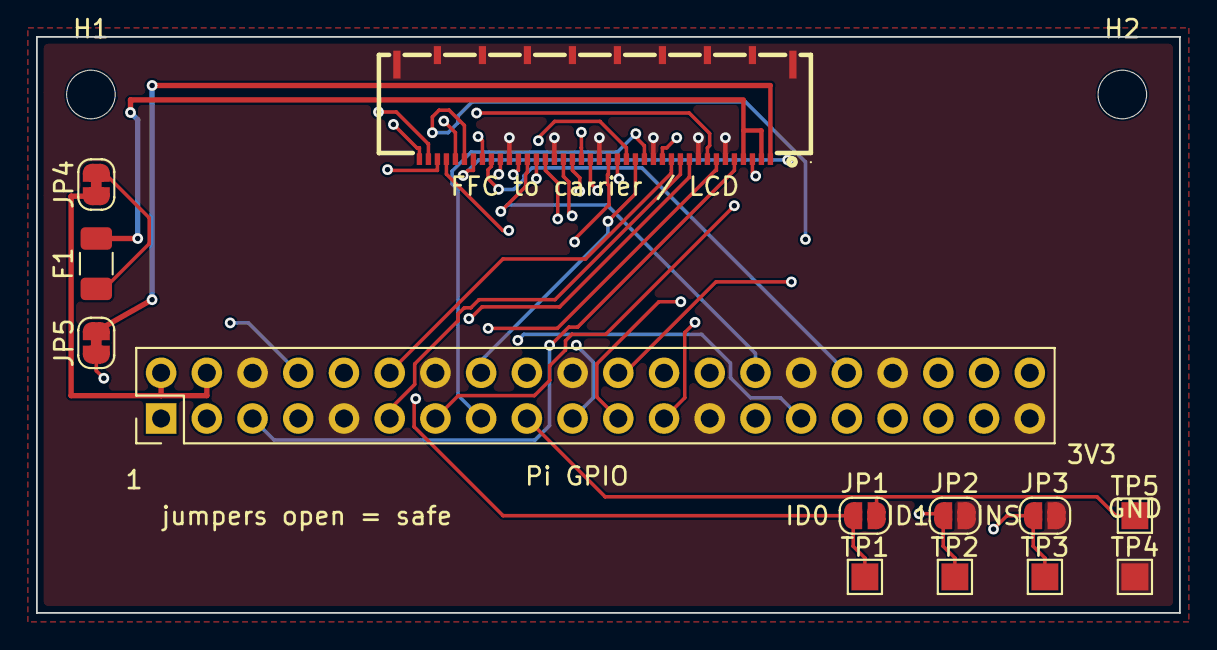
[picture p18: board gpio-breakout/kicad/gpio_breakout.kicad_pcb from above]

Board: 4 copper layers, 63.5 x 32.0 mm, 15 parts (0 on the bottom side), 37 nets.

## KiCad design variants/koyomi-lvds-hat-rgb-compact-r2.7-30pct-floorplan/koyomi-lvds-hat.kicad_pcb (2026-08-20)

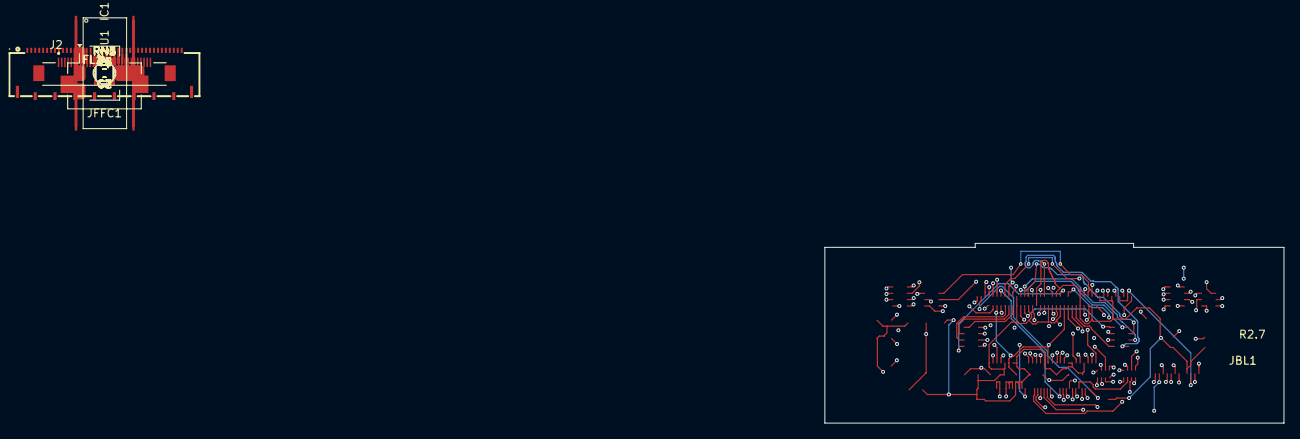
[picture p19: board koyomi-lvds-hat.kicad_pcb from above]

Board: 4 copper layers, 58.0 x 22.7 mm, 29 parts (0 on the bottom side), 78 nets.

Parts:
C1, C4: 1uF; C_0603_1608Metric_Pad1.08x0.95mm_HandSolder
C2, C5: 100nF; C_0603_1608Metric_Pad1.08x0.95mm_HandSolder
C3, C6: 10nF; C_0603_1608Metric_Pad1.08x0.95mm_HandSolder
C7, C8: 4.7uF; C_0603_1608Metric_Pad1.08x0.95mm_HandSolder
FL1, FL2: DLP2ADN121HL4L; Murata_DLP2ADN121HL4L
H1, H2, H3, H4: MountingHole; RPi_Hat_Mounting_Hole
IC1: SN75LVDS83B; TSSOP56
J2: 20374-R30E-31; I-PEX_20374-R30E-31
JBL1: BACKLIGHT FFC-12; Hirose_FH12-12S-0.5SH_1x12-1MP_P0.50mm_Horizontal
JFFC1: FH41-40S-0.5SH(05) / C596805; FPC-SMD_FH41-40S-0.5SH
JP1: CLKSEL; SolderJumper-2_P1.3mm_Open_RoundedPad1.0x1.5mm
JP2: SHTDN; SolderJumper-2_P1.3mm_Open_RoundedPad1.0x1.5mm
R1, R2: 4.7K; R_0603_1608Metric_Pad0.98x0.95mm_HandSolder
RN1, RN2, RN3, RN4, RN5, RN6: 47; R_Array_Convex_4x0603
U1: AP2114H-2.5; SOT-223-3_TabPin2

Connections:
+2V5: C4.1, C5.1, C6.1, C8.1, J2.4, J2.5, J2.6, U1.2 (VO)
+3V3: C1.1, C2.1, C3.1, C7.1, IC1.1 (IOVCC@1), IC1.9 (VCC@1), IC1.26 (IOVCC@2), IC1.34 (PLLVCC), IC1.44 (LVDSVCC), JFFC1.1 (3.3V), R1.1, R2.1, U1.3 (VI)
+5V: JBL1.10, JFFC1.2 (5V), JFFC1.4 (5V)
B0: JFFC1.7 (BCM4_GPCLK0), RN1.7 (R2.2)
B1: JFFC1.29 (BCM5), RN4.8 (R1.2)
B2: JFFC1.31 (BCM6), RN5.5 (R4.2)
B3: JFFC1.26 (BCM7_CE1), RN3.8 (R1.2)
B4: JFFC1.24 (BCM8_CE0), RN3.7 (R2.2)
B5: JFFC1.21 (BCM9_MISO), RN3.6 (R3.2)
CLKIN: JFFC1.27 (BCM0_ID_SD), RN4.7 (R2.2)
CLKSEL: IC1.17 (CLKSEL), JP1.1 (A), R1.2
D0: IC1.51 (D0), RN5.1 (R1.1)
D1: IC1.52 (D1), RN2.3 (R3.1)
D2: IC1.54 (D2), RN2.2 (R2.1)
D3: IC1.55 (D3), RN6.4 (R4.1)
D4: IC1.56 (D4), RN6.3 (R3.1)
D6: IC1.3 (D6), RN6.2 (R2.1)
D7: IC1.4 (D7), RN3.5 (R4.2)
D8: IC1.6 (D8), RN4.4 (R4.1)
D9: IC1.7 (D9), RN5.3 (R3.1)
D12: IC1.11 (D12), RN5.2 (R2.1)
D13: IC1.12 (D13), RN1.1 (R1.1)
D14: IC1.14 (D14), RN2.4 (R4.1)
D15: IC1.15 (D15), RN1.2 (R2.1)
D18: IC1.19 (D18), RN4.1 (R1.1)
D19: IC1.20 (D19), RN5.4 (R4.1)
D20: IC1.22 (D20), RN3.1 (R1.1)
D21: IC1.23 (D21), RN3.2 (R2.1)
D22: IC1.24 (D22), RN3.3 (R3.1)
D24: IC1.27 (D24), RN1.3 (R3.1)
D25: IC1.28 (D25), RN1.4 (R4.1)
D26: IC1.30 (D26), RN4.3 (R3.1)
EN: JBL1.12, JFFC1.13 (BCM27)
ENABLE: JFFC1.28 (BCM1_ID_SC), RN4.6 (R3.2)
G0: JFFC1.19 (BCM10_MOSI), RN3.4 (R4.1)
G1: JFFC1.23 (BCM11_SCLK), RN4.5 (R4.2)
G2: JFFC1.32 (BCM12_PWM0), RN5.6 (R3.2)
G3: JFFC1.33 (BCM13_PWM1), RN5.7 (R2.2)
G4: JFFC1.8 (BCM14_TXD), RN1.8 (R1.2)
G5: JFFC1.10 (BCM15_RXD), RN2.5 (R4.2)
GND: C1.2, C2.2, C3.2, C4.2, C5.2, C6.2, C7.2, C8.2, IC1.2 (D5), IC1.5 (GND@1), IC1.8 (D10), IC1.10 (D11), IC1.13 (GND@2), IC1.16 (D16), IC1.18 (D17), IC1.21 (GND@3), IC1.25 (D23), IC1.29 (GND@4), IC1.33 (GND@5), IC1.35 (GND@6), IC1.36 (GND@7), IC1.43 (GND@8), IC1.49 (GND@9), IC1.50 (D27), IC1.53 (GND@10), J2.7, J2.8, J2.9, J2.S1 (SHIELD), J2.S2 (SHIELD__1), JBL1.9, JFFC1.6 (GND), JFFC1.9 (GND), JFFC1.14 (GND), JFFC1.20 (GND), JFFC1.25 (GND), JFFC1.30 (GND), JP1.2 (B), JP2.2 (B), U1.1 (GND)
HSYNC: JFFC1.5 (BCM3_SCL), RN1.6 (R3.2)
LCD_INS: J2.30, JFFC1.39 (GND)
L_CLKIN: IC1.31 (CLKIN), RN4.2 (R2.1)
unnamed: FL2.3, IC1.40 (CLCKOUTM)
unnamed: FL2.1, IC1.39 (CLCKOUTP)
unnamed: FL1.7, IC1.48 (Y0M)
unnamed: FL1.5, IC1.47 (Y0P)
unnamed: FL1.3, IC1.46 (Y1M)
unnamed: FL1.1, IC1.45 (Y1P)
unnamed: FL2.7, IC1.42 (Y2M)
unnamed: FL2.5, IC1.41 (Y2P)
PANEL_ID0: J2.10, JFFC1.17 (3.3V)
PANEL_ID1: J2.21, JFFC1.34 (GND)
PWM: JBL1.11, JFFC1.37 (BCM26)
R0: JFFC1.36 (BCM16), RN5.8 (R1.2)
R1: JFFC1.11 (BCM17), RN2.6 (R3.2)
R2: JFFC1.12 (BCM18_PCM_C), RN2.7 (R2.2)
R3: JFFC1.35 (BCM19_MISO_PCM_FS), RN6.5 (R4.2)
R4: JFFC1.38 (BCM20_MOSI_PCM_DI), RN6.6 (R3.2)
R5: JFFC1.40 (BCM21_SCLK_PCM_DO), RN6.7 (R2.2)
RX0+: FL1.6, J2.28
RX0-: FL1.8, J2.29
RX1+: FL1.2, J2.26
RX1-: FL1.4, J2.27
RX2+: FL2.6, J2.24
RX2-: FL2.8, J2.25
RXCLK+: FL2.2, J2.22
RXCLK-: FL2.4, J2.23
SHTDN: IC1.32 (~SHTDN), JP2.1 (A), R2.2
VAD: J2.1, J2.2, JBL1.7
VCD1: J2.18, JBL1.6
VCD2: J2.17, JBL1.5
VCD3: J2.16, JBL1.4
VCD4: J2.15, JBL1.3
VCD5: J2.14, JBL1.2
VCD6: J2.13, JBL1.1
VSYNC: JFFC1.3 (BCM2_SDA), RN1.5 (R4.2)

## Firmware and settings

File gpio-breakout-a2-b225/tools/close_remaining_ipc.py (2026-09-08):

"""Close native DRC opens by reusing existing escaped through vias."""
import json
from update_addon_ipc import session,D
from native_astar import _astar_multilayer
from route_addon_ipc import copper
report=json.loads((D/'reports/drc.json').read_text());results=[]
with session(D/'gpio_breakout.kicad_pcb') as k:
 b=k.get_board();nets={n.name:n for n in b.get_nets()};fps={f.reference_field.text.value:f for f in b.get_footprints()}
 for finding in report['unconnected_items']:
  net=finding['items'][0]['description'].split('[')[1].split(']')[0];v=next(v for v in b.get_vias() if v.net.name==net);q=next(p for p in fps['J2'].definition.pads if p.net.name==net);origin=(v.position.x/1e6,v.position.y/1e6);goal=(q.position.x/1e6,q.position.y/1e6);done=False
  for layer in [34,5,3]:
   try:
    path=_astar_multilayer(b,net,origin,goal,layers=(34,5,3),width_mm=.2,via_diameter_mm=.5,step=.1,goal_layer=None,clearance_mm=.23,start_layer=layer,board_bounds=(50.65,112.85,50.65,81.35),max_states=350000,via_clearance_mm=.23,via_endpoint_keepout_mm=.7)
    count=copper(b,nets[net],path);b.save();results.append(dict(net=net,items=count,layer=layer));done=True;break
   except RuntimeError as e:print(net,layer,str(e),flush=True)
  if not done:results.append(dict(net=net,status='pending'))
 b.refill_zones();b.save()
(D/'reports/closure.json').write_text(json.dumps(results,indent=2)+'\n');print(results)

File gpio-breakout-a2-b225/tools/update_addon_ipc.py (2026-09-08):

"""Native KiCad migration from immutable GPIO A1 to LCD-only B2.25 A2."""
import copy,json,os,subprocess,tempfile,time,uuid
from pathlib import Path
from contextlib import contextmanager
from kipy import KiCad
from kipy.schematic import Schematic
from kipy.proto.common.types import DocumentType
from kipy.proto.schematic import schematic_types_pb2
from kipy.schematic_types import GlobalLabel,NoConnectMarker,SchematicSymbolInstance
from kipy.board_types import FootprintInstance,Net,BoardText,BoardLayer
from kipy.geometry import Vector2,Angle
from google.protobuf import descriptor_pool,message_factory
D=Path(__file__).resolve().parents[1]
CLI=os.environ.get('KICAD_CLI','/Users/hyper/projects/tensorfleet/vaio_p_modding/tools/kicad11-b2231-parity/KiCad.app/Contents/MacOS/kicad-cli')
CARRIER=Path(os.environ.get('B225_SOURCE','/private/tmp/carrier-b225-usbc-outward/kicad-b2.25-a2-combined-io'))
@contextmanager
def session(path):
 with tempfile.TemporaryDirectory(prefix='ga-',dir='/private/tmp') as temp:
  sock=Path(temp)/'a.sock'
  with tempfile.TemporaryFile(mode='w+t') as log:
   cli=os.environ.get('KICAD_SCH_CLI',CLI) if str(path).endswith('.kicad_sch') else CLI
   proc=subprocess.Popen([cli,'api-server','--socket',str(sock),str(path)],stdout=log,stderr=log)
   try:
    end=time.monotonic()+60
    while not sock.exists():
     if proc.poll() is not None or time.monotonic()>end:log.seek(0);raise RuntimeError(log.read() or 'IPC timeout')
     time.sleep(.1)
    k=KiCad(socket_path='ipc://'+str(sock),timeout_ms=10000)
    for i in range(100):
     try:k.ping();break
     except Exception:time.sleep(.1)
    yield k
   finally:proc.terminate();proc.wait(timeout=10)
def sheets(k):
 root=Schematic(k._client,k.get_open_documents(DocumentType.DOCTYPE_SCHEMATIC)[0]);out=[]
 def visit(inst):
  doc=copy.deepcopy(root.document);doc.sheet_path.CopyFrom(inst.path.proto);out.append(Schematic(root.client,doc))
  for c in inst.children:visit(c)
 for inst in root.get_hierarchy():visit(inst)
 return root,out

def pins(sym):
 out={}
 for child in sym.proto.definition.items:
  if child.item.type_url.endswith('SchematicPin'):
   p=schematic_types_pb2.SchematicPin();child.item.Unpack(p);out[p.number]=p
 return out

def shift(sym,x,y):
 dx=round(x*1e6)-sym.position.x;dy=round(y*1e6)-sym.position.y;sym.position=Vector2.from_xy_mm(x,y)
 def translate(msg):
  for field,value in msg.ListFields():
   if field.cpp_type!=field.CPPTYPE_MESSAGE:continue
   for child in (value if field.label==field.LABEL_REPEATED else [value]):
    if child.DESCRIPTOR.full_name=='kiapi.common.types.Vector2':child.x_nm+=dx;child.y_nm+=dy
    else:translate(child)
 for name in ['reference_field','value_field','footprint_field','datasheet_field','description_field']:
  f=getattr(sym,name);v=f.text.position;v.x+=dx;v.y+=dy;f.text.position=v
 for child in sym.definition.items:
  msg=message_factory.GetMessageClass(descriptor_pool.Default().FindMessageTypeByName(child.item.TypeName()))();child.item.Unpack(msg);translate(msg);child.item.Pack(msg)

PI={1:'+3V3',2:'+5V',3:'GPIO2',4:'+5V',5:'GPIO3',6:'GND',7:'GPIO4',8:'GPIO14',9:'GND',10:'GPIO15',11:'GPIO17',12:'GPIO18',13:'GPIO27',14:'GND',15:'GPIO22',16:'GPIO23',17:'+3V3',18:'GPIO24',19:'GPIO10',20:'GND',21:'GPIO9',22:'GPIO25',23:'GPIO11',24:'GPIO8',25:'GND',26:'GPIO7',27:'ID_SD',28:'ID_SC',29:'GPIO5',30:'GND',31:'GPIO6',32:'GPIO12',33:'GPIO13',34:'GND',35:'GPIO19',36:'GPIO16',37:'GPIO26',38:'GPIO20',39:'GND',40:'GPIO21'}
aliases={'CS_GPIO24':'GPIO24','BL_GPIO18':'GPIO18','MISO_GPIO19':'GPIO19','MOSI_GPIO20':'GPIO20','SCLK_GPIO21':'GPIO21','+5V':'+5V_FFC','+3V3_PI':'+3V3_FFC'}
source=json.loads((D/'reports/carrier-interface-source.json').read_text())
FFC={str(v['pin']):None if v['pin'] in [1,2,3,4,6,7] else aliases.get(v['carrier'],v['carrier']) for v in source['pin_map']}
MAP={'J1':FFC,'J2':{str(n):v for n,v in PI.items()},'F1':{'1':'+5V_LNK','2':'+5V_FFC'},'JP4':{'1':'+5V','2':'+5V_LNK'},'JP5':{'1':'+3V3','2':'+3V3_FFC'},'TP4':{'1':'GND'},'TP5':{'1':'+3V3'},'#FLG1':{'1':'+3V3'},'#FLG2':{'1':'+5V'},'#FLG3':{'1':'GND'}}
REMOVE={'JP1','JP2','JP3','TP1','TP2','TP3'}
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

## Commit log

2026-08-11 Add half-area compact RGB FFC floorplan
    [interface-pinout.csv, koyomi-lvds-hat.kicad_pcb, koyomi-lvds-hat.kicad_sch]
2026-08-11 Add single-side compact RGB floorplan
    [interface-pinout.csv, koyomi-lvds-hat.kicad_pcb, koyomi-lvds-hat.kicad_sch]
2026-08-11 Add consolidated LCD backlight FFC
    [backlight-interface-pinout.csv, interface-pinout.csv, koyomi-lvds-hat.kicad_pcb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]
2026-08-11 Finish compact RGB LVDS R2.3 routing
    [backlight-interface-pinout.csv, interface-pinout.csv, koyomi-lvds-hat.kicad_pcb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]
2026-08-13 Add compact LCD controller print model
    [koyomi-rgb-compact-r2.3-print-mockup.step, koyomi-rgb-compact-r2.3-print-mockup.stl]
2026-08-13 Route compact LCD panel sidebands over FFC
    [backlight-interface-pinout.csv, interface-pinout.csv, koyomi-lvds-hat.kicad_pcb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]
2026-08-13 Release compact RGB LCD R2.6 fabrication candidate
    [backlight-interface-pinout.csv, bom.csv, interface-pinout.csv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]
2026-08-18 Add 30 percent smaller LCD floorplan
    [backlight-interface-pinout.csv, interface-pinout.csv, koyomi-lvds-hat.kicad_pcb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]
2026-08-18 Orient LCD edge connectors outward
    [koyomi-lvds-hat.kicad_pcb, koyomi-rgb-compact-r2.7-print-mockup.step, koyomi-rgb-compact-r2.7-print-mockup.stl]
2026-08-18 Route compact R2.7 fabrication work in progress
    [koyomi-lvds-hat.kicad_pcb]
2026-08-20 Add gpio-breakout A0: 40-pin FFC to Pi GPIO bench adapter
    FH41-40S FFC (JDISP1/JFFC1 system) broken out 1:1 to a standard Pi
    40-pin header so a stock Pi can drive the Koyomi chain over the
    production FFC. Pins 17/34/39 (PANEL_ID0/PANEL_ID1/LCD_INS) are
    isolated behind default-open solder jumpers with test pads — never
    hard-wired to the Pi's 3V3/GND. ERC 0, DRC 0/0/0, fully routed,
    renders included. Headless generators in gpio-breakout/tools/.
    [gpio_breakout.kicad_pcb, gpio_breakout.kicad_sch]
2026-08-20 gpio-breakout: attach FH41 STEP model, tidy silk
    Real connector model from the shared B2_INTERCONNECT.3dshapes now
    renders on J1; redundant 3V3/GND silk texts removed (TP refs + README
    cover them).
    [gpio_breakout.kicad_pcb]
2026-08-20 Finish compact R2.7 LCD fabrication candidate
    [bom.csv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]
2026-08-20 gpio-breakout A1: address design review
    4-layer with solid In1 GND plane + pours (review #2), corrected FH41
    land pattern 0.30x0.65 with paste margin (#4), pads 41-50 shield to
    GND (#4), fused + default-bridged/cuttable 5V/3V3 links (#3), symbol
    pins retyped passive (#7), fresh all-severity ERC/DRC committed (#6,
    #7), J2 assembly split defined (#9), honest gate statements in README
    (#2, #8). Board grown to 63.5x32 for full routing: errors-only DRC
    0/0/0, zero dangling copper. Fabrication remains gated on the
    interconnect contract cable identity (#1, #5).
    [gpio_breakout.kicad_pcb, gpio_breakout.kicad_sch]
2026-08-20 gpio-breakout: move backside cut-links silk inboard
    The two instruction lines were center-anchored at x=3.2 and ran off
    the left board edge. Now at x=16 above the version text; generator
    source synced; bottom render regenerated.
    [gpio_breakout.kicad_pcb]
2026-08-20 gpio-breakout A1: JLCPCB order package
    Gerbers (4-layer), drill + map, JLC BOM/CPL (two placed parts: J1
    C596805, F1 pinned to C106264 PTC), SHA256SUMS, order README. J2 and
    jumpers documented as not-placed. F1 LCSC synced into netlist source.
    [bom.csv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]
2026-08-20 gpio-breakout: drop 'FFC contacts face DOWN' silk
    The line printed across the FH41 connector outline. Removed from the
    board and generator; gerber package + checksums + top render
    regenerated. Cable contact orientation remains documented in the
    README and order package notes.
    [gpio_breakout-B_Cu.gbl, gpio_breakout-B_Mask.gbs, gpio_breakout-B_Silkscreen.gbo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]
2026-09-08 GPIO LCD A2: B2.25 interface and protected USB2 host input (#5)
    * Add GPIO LCD A2 adapter for B2.25 Samtec interface
    * Add protected USB2 input to B2.25 GPIO LCD addon
    * Document C1 as the GPIO A2 LCD endpoint
    * Restore GPIO A2 connector solder paste and review bench-use limits
    [C_0603_1608Metric.step, Molex_1054500101_official.stp, R_0603_1608Metric.step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]
2026-09-08 Correct GPIO A2 JLC stackup and qualify bench power paths
    [gpio_breakout.kicad_pcb]
2026-09-09 Add GPIO A2 USB soft start and Pi-side display series provisions
    [gpio_breakout.kicad_pcb, gpio_breakout.kicad_sch, interface-pinout.csv]

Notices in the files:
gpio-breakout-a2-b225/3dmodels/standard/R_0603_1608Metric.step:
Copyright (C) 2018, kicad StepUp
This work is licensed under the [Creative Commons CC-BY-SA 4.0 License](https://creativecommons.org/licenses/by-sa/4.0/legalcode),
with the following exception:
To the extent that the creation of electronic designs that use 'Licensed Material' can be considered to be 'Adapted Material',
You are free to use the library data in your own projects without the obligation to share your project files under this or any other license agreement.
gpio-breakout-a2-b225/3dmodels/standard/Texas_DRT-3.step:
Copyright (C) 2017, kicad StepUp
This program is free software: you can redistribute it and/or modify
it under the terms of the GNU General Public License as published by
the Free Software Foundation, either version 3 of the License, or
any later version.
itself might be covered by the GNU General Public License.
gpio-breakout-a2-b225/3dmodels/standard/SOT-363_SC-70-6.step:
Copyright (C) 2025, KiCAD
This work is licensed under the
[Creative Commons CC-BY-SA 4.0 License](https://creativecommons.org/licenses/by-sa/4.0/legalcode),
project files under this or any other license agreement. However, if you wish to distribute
